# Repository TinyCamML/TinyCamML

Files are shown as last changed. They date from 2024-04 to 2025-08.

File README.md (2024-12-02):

# The Boron & OpenMV TinyCamML: 
### A small field-deployable camera with a cell connection.



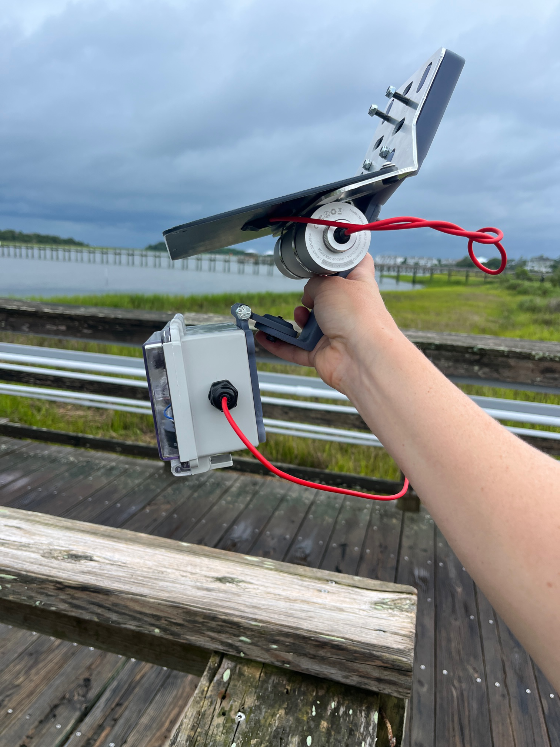
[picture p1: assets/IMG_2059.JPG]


### Overview:
Have you ever wanted to deploy a field camera, use machine learning on the images, and then send some message via cell? Us too! This repository is our work-in-progress on building the camera of our dreams. 

Our initial goal is to build cameras that overlook roadways, take pictures of the road, determine if the roadway is flooded, and send a simple message (i.e., 'flooded' or 'not flooded') via cell to a google sheet. 

The repository has multiple parts:

- a `Firmware` folder, that contains the OpenMV code and the Particle Boron code. The OpenMV handles taking pictures and using a ML model. The Boron handles publishing the ML model results to a google sheet via cell. 
- a `hardware` folder, that contains the 3D primnted parts, the circuit diagram, and the bill of materials for building the camera and the housing. 
- a `dev` folder, that has some snippets of code that were useful in building, testing, adn debugging the device
- an assets folder, that contains a [pdf of a build guide](assets/2024_12_02_BuildGuide.pdf) for the TinyCamML. If you have comments, you can add them to our [google document of the build guide](https://docs.google.com/document/d/1C9PLoJusVJ-cXYZn4gjNS5eJlwIkASh2FyWyaLo89QA/edit?usp=sharing)

### Do you want to be involved?:

- Get in touch with us, we would be happy to collaborate!
- Read through the repository to look at the files/code we provide.
-Check out the open issues and participate in our discussion.

### Code of Conduct:
We intend to foster an inclusive and respectful environment surrounding the contribution and discussion of our project. Make sure you understand our Code of Conduct.

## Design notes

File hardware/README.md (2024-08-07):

#  The Boron + OpenMV TinyCamML has 7 printed parts:

- 5 Mounting Parts
  -  Solar_panel_mount.stl
  -  Visor.stl
  -  Polycase_mount.stl
  -  XY_bracket
  -  Exteneder.stl
- 2 Baseplate Parts
  -  Baseplate.stl
  -  Antenna_mount.stl
######
## Images
# Full Build Assembly
  



# Mounting Assembly



# Baseplate Assembly



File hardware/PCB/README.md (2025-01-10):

# Directory for Carrier Board PCB.

Contains Eagle Schematic, Board Layout, CAM Data, and BoM for the PCB.

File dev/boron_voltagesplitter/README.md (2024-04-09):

# TestingVoltageSplitter

This firmware project was created using [Particle Developer Tools](https://www.particle.io/developer-tools/) and is compatible with all [Particle Devices](https://www.particle.io/devices/).

Feel free to replace this README.md file with your own content, or keep it for reference.

## Table of Contents
- [Introduction](#introduction)
- [Prerequisites To Use This Template](#prerequisites-to-use-this-repository)
- [Getting Started](#getting-started)
- [Particle Firmware At A Glance](#particle-firmware-at-a-glance)
  - [Logging](#logging)
  - [Setup and Loop](#setup-and-loop)
  - [Delays and Timing](#delays-and-timing)
  - [Testing and Debugging](#testing-and-debugging)
  - [GitHub Actions (CI/CD)](#github-actions-cicd)
  - [OTA](#ota)
- [Support and Feedback](#support-and-feedback)
- [Version](#version)

## Introduction

For an in-depth understanding of this project template, please refer to our [documentation](https://docs.particle.io/firmware/best-practices/firmware-template/).

## Prerequisites To Use This Repository

To use this software/firmware on a device, you'll need:

- A [Particle Device](https://www.particle.io/devices/).
- Windows/Mac/Linux for building the software and flashing it to a device.
- [Particle Development Tools](https://docs.particle.io/getting-started/developer-tools/developer-tools/) installed and set up on your computer.
- Optionally, a nice cup of tea (and perhaps a biscuit).

## Getting Started

1. While not essential, we recommend running the [device setup process](https://setup.particle.io/) on your Particle device first. This ensures your device's firmware is up-to-date and you have a solid baseline to start from.

2. If you haven't already, open this project in Visual Studio Code (File -> Open Folder). Then [compile and flash](https://docs.particle.io/getting-started/developer-tools/workbench/#cloud-build-and-flash) your device. Ensure your device's USB port is connected to your computer.

3. Verify the device's operation by monitoring its logging output:
    - In Visual Studio Code with the Particle Plugin, open the [command palette](https://docs.particle.io/getting-started/developer-tools/workbench/#particle-commands) and choose "Particle: Serial Monitor".
    - Or, using the Particle CLI, execute:
    ```
    particle serial monitor --follow
    ```

4. Uncomment the code at the bottom of the cpp file in your src directory to publish to the Particle Cloud! Login to console.particle.io to view your devices events in real time.

5. Customize this project! For firmware details, see [Particle firmware](https://docs.particle.io/reference/device-os/api/introduction/getting-started/). For information on the project's directory structure, visit [this link](https://docs.particle.io/firmware/best-practices/firmware-template/#project-overview).

## Particle Firmware At A Glance

### Logging

The firmware includes a [logging library](https://docs.particle.io/reference/device-os/api/logging/logger-class/). You can display messages at different levels and filter them:

```
Log.trace("This is trace message");
Log.info("This is info message");
Log.warn("This is warn message");
Log.error("This is error message");
```

### Setup and Loop

Particle projects originate from the Wiring/Processing framework, which is based on C++. Typically, one-time setup functions are placed in `setup()`, and the main application runs from the `loop()` function.

For advanced scenarios, explore our [threading support](https://docs.particle.io/firmware/software-design/threading-explainer/).

### Delays and Timing

By default, the setup() and loop() functions are blocking whilst they run, meaning that if you put in a delay, your entire application will wait for that delay to finish before anything else can run. 

For techniques that allow you to run multiple tasks in parallel without creating threads, checkout the code example [here](https://docs.particle.io/firmware/best-practices/firmware-template/).

(Note: Although using `delay()` isn't recommended for best practices, it's acceptable for testing.)

### Testing and Debugging

For firmware testing and debugging guidance, check [this documentation](https://docs.particle.io/troubleshooting/guides/build-tools-troubleshooting/debugging-firmware-builds/).

### GitHub Actions (CI/CD)

This project provides a YAML file for GitHub, automating firmware compilation whenever changes are pushed. More details on [Particle GitHub Actions](https://docs.particle.io/firmware/best-practices/github-actions/) are available.

### OTA

To learn how to utilize Particle's OTA service for device updates, consult [this documentation](https://docs.particle.io/getting-started/cloud/ota-updates/).

Test OTA with the 'Particle: Cloud Flash' command in Visual Studio Code or the CLI command 'particle flash'!

This firmware supports binary assets in OTA packages, allowing the inclusion of audio, images, configurations, and external microcontroller firmware. More details are [here](https://docs.particle.io/reference/device-os/api/asset-ota/asset-ota/).

## Support and Feedback

For support or feedback on this template or any Particle products, please join our [community](https://community.particle.io)!

## Version

Template version 1.0.2

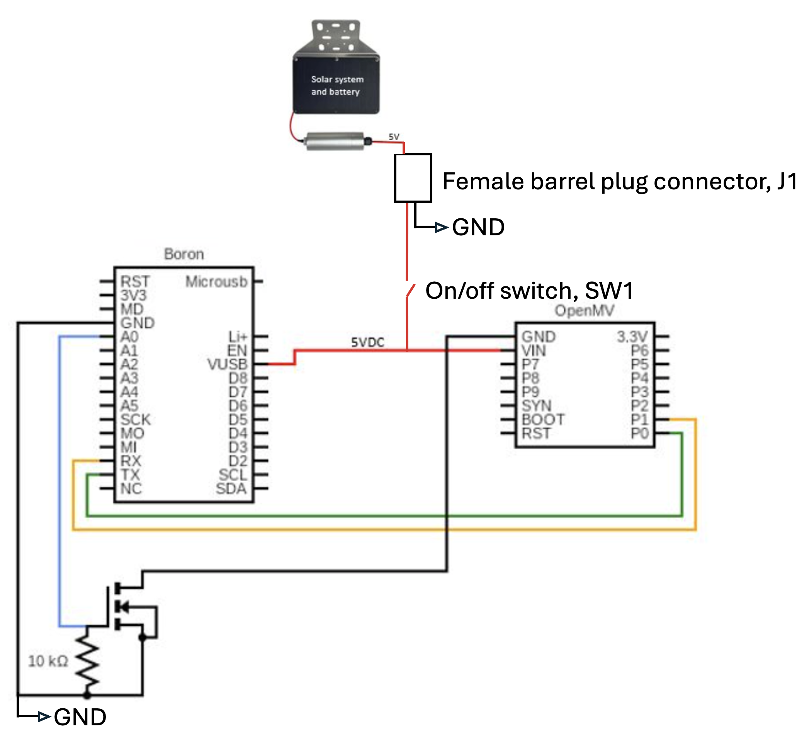
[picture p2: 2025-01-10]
hardware/TinyCamMLCircuit.png

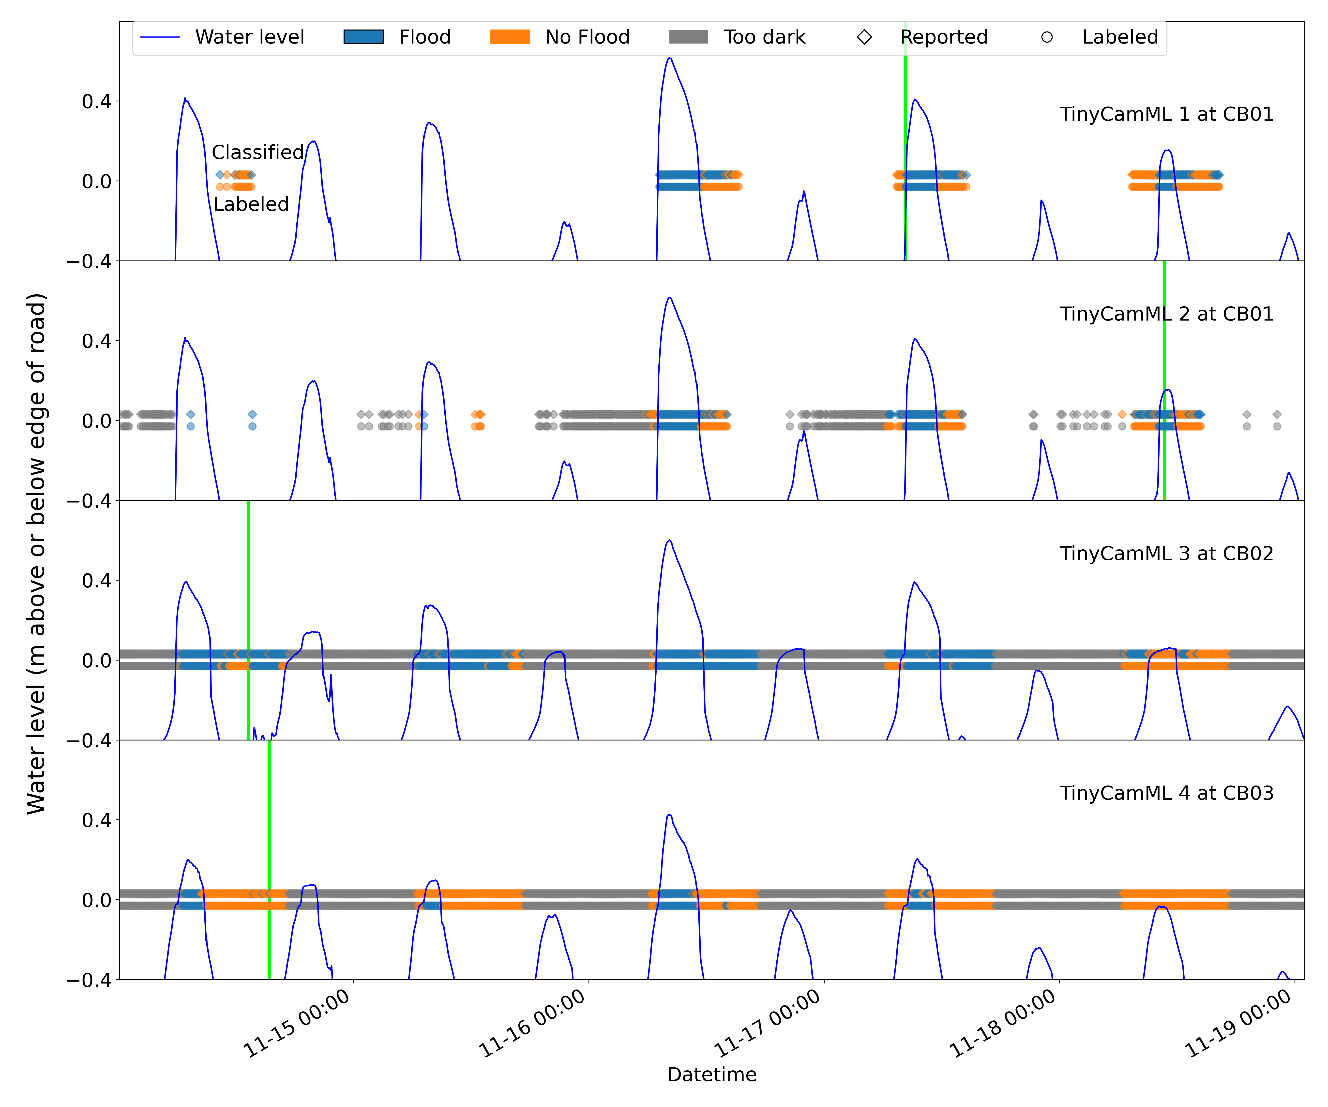
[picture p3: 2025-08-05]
Data Analysis/Figures/Figure3-WL.png

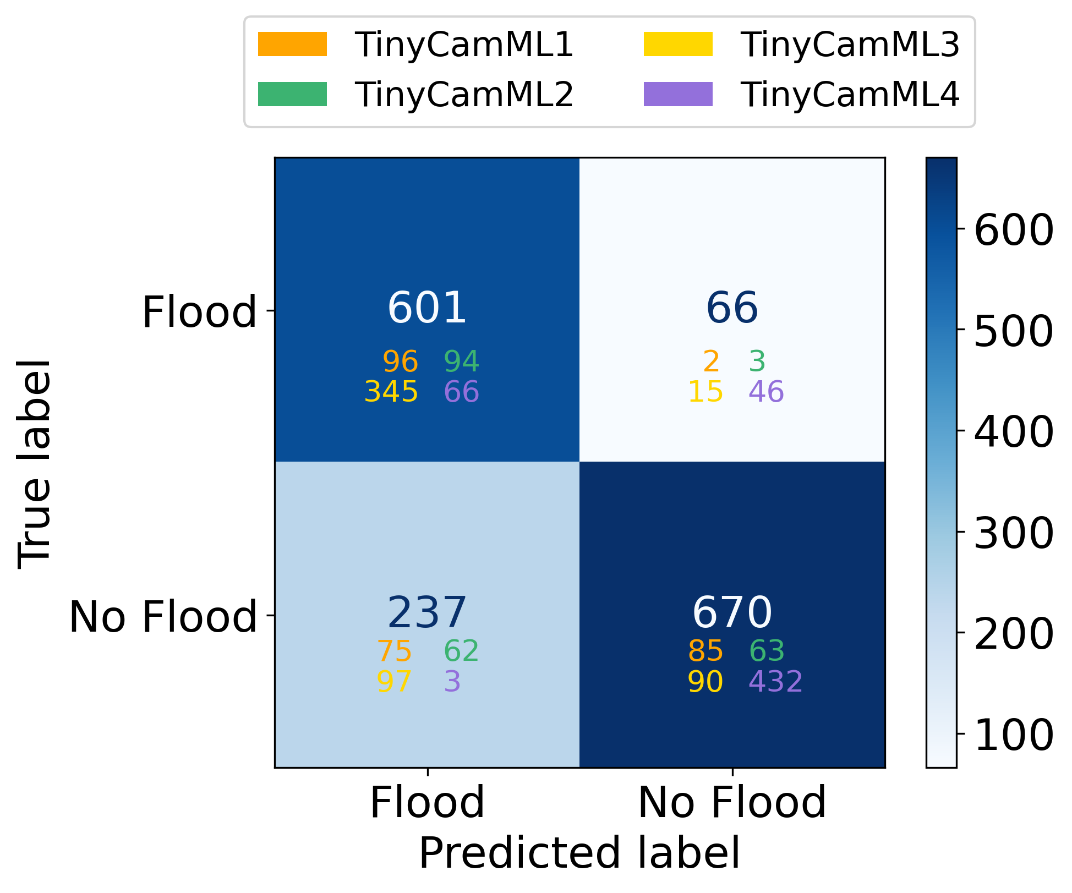
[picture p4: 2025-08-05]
Data Analysis/Figures/Figure4-CM.png

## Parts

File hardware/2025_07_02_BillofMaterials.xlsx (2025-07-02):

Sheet: BOM V2
 | For TinyCamML with PCB board
Parts | Price ($) | Picture | Link | Notes
Main Components
5W 5V solar system | 99 |  | https://voltaicsystems.com/5-watt-5-volt-35wh-solar-system/
OpenMV Cam H7 Plus | 85 |  | https://openmv.io/products/openmv-cam-h7-plus
Micro SD card | 10.94 |  | https://www.amazon.com/Samsung-Plus-Micro-Memory-Adapter/dp/B07349L1WS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 | Needed for the OpenMV
Particle Boron | 48.95 |  | https://store.particle.io/products/boron-lte-cat-m1-noram-with-ethersim-4th-gen
Custom TinyCamML PCB Board | 9.85 |  | https://github.com/TinyCamML/TinyCamML/tree/main/hardware/PCB | can order from oshpark.com
N Channel MosFET switch 30V/60a | 2.25 |  | https://www.adafruit.com/product/355
Resistors | 8.49 |  | https://www.sparkfun.com/products/10969
Switch slide | 0.44 |  | https://a.co/d/dqLmGOT | https://www.digikey.com/en/products/detail/same-sky-formerly-cui-devices/ds01-254-s-01be/11310868
Power jack for barrel plug | 0.79 |  | https://www.digikey.com/en/products/detail/w%C3%BCrth-elektronik/694102303002/5047520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
16 piece female headers | 0.82 |  | https://www.digikey.com/en/products/detail/sullins-connector-solutions/PPTC161LFBN-RC/810154
12 piece female header | 0.67 |  | https://www.digikey.com/en/products/detail/sullins-connector-solutions/PPTC121LFBN-RC/807231
Polycase WH-02-02 Clear | 21.03 |  | https://www.polycase.com/wh-02?gad_source=1 | assembly includes gasketed enclosure, 4 external mounting feet, and 4 screws
PG-9 size cable gland | 1.95 |  | https://www.adafruit.com/product/761
3D Printed Parts
For mounting the external housing: | 59.7 |  | https://formlabs.com/store/materials/tough-2000-resin/
XY Bracket |  |  | https://github.com/TinyCamML/Boron-and-OpenMV/blob/main/hardware/3D_Printed_Parts/XY_part%20_v4.stl
Extender |  |  | https://github.com/TinyCamML/Boron-and-OpenMV/tree/main/hardware/3D_Printed_Parts
Polycase Mount |  |  | https://github.com/TinyCamML/Boron-and-OpenMV/blob/main/hardware/polycase_mount_v5.stl
Solar Panel mount |  |  | https://github.com/TinyCamML/Boron-and-OpenMV/blob/main/hardware/3D_Printed_Parts/solar_panel_mount_v4.stl
Visor (optional) |  |  | https://github.com/TinyCamML/Boron-and-OpenMV/blob/main/hardware/3D_Printed_Parts/visor.stl
For mounting internal electronics:
Antenna Mount |  |  | https://github.com/TinyCamML/Boron-and-OpenMV/blob/main/hardware/3D_Printed_Parts/antenna_mount_v4.stl
Baseplate |  |  | https://github.com/TinyCamML/TinyCamML/blob/main/hardware/3D_Printed_Parts/baseplate_pcb_final.stl
Physical hardware
For the mount + housing:
1/4-in x 2-1/2-in Stainless Coarse Thread Hex Bolt | 0.3268 |  | https://www.mcmaster.com/catalog/130/3587/92198A552
1/4-in x 20 Stainless Steel Stainless Steel Nylon Insert Nut | 0.1254 |  | https://www.mcmaster.com/catalog/130/3644/91831A029
18-8 Stainless Steel Socket Head Screw, M5 x 0.8 mm Thread, 20 mm Long | 1.1662 |  | https://www.mcmaster.com/catalog/130/3558/91292A128
18-8 Stainless Steel Hex Nut M5 x 0.8 mm Thread | 0.6839 |  | https://www.mcmaster.com/catalog/130/3634/91828A241
4-40 Thread Size, 3/8" Long socket head screw | 0.2336 |  | https://www.mcmaster.com/92196A108/
M4 x 8mm Phillips thread rolling screws | 0.4112 |  | https://www.mcmaster.com/catalog/130/3444/90116A205
4-40 nuts | 0.1556 |  | https://www.mcmaster.com/91841A005/
#8-16 x .31” screws | 0 |  |  | comes with the polycase
Miscellaneous
Hoseclamps
Dessicant pack | 0.1798 |  | https://www.amazon.com/Dry-Premium-Packets-Desiccant-Dehumidifiers/dp/B00DYKTS9C?hvadid=695574715858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
O-ring grease | 1.49 |  | https://www.amazon.com/Ring-Grease-Waterproof-Insulating-Smoothness/dp/B0DKTPFCHC?hvadid=616863385083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
Sum | 354.6525

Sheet: BOM V1
 | For TinyCamML without PCB board
Parts | Quantity Needed to build one | Picture | Link | Notes
Main Components
5W 5V solar system | 1 |  | https://voltaicsystems.com/5-watt-5-volt-35wh-solar-system/
Female 3.5x1.1mm - MicroUSB | 1 |  | https://voltaicsystems.com/A101
OpenMV Cam H7 Plus | 1 |  | https://openmv.io/products/openmv-cam-h7-plus
Micro SD card | 1 |  | https://www.amazon.com/Samsung-Plus-Micro-Memory-Adapter/dp/B07349L1WS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 | Needed for the OpenMV
Particle Boron | 1 |  | https://store.particle.io/products/boron-lte-cat-m1-noram-with-ethersim-4th-gen
N Channel MosFET switch 30V/60a | 1 |  | https://www.adafruit.com/product/355
1 in x 1 in Protoboard | 1 |  | https://www.amazon.com/gp/product/B0BK76L5BD/ref=ox_sc_act_title_1?smid=A3M1L3DLN3L91I&psc=1 | This ones' rows are not shorted so in future orders, I'd recommend a different one
Resistors | 1 10k ohm resistor |  | https://www.sparkfun.com/products/10969
Polycase WH-02-02 Clear | 1 |  | https://www.polycase.com/wh-02?gad_source=1 | assembly includes gasketed enclosure, 4 external mounting feet, and 4 screws
PG-9 size cable gland | 1 |  | https://www.adafruit.com/product/761
3D Printed Parts
For mounting the external housing: |  |  | https://formlabs.com/store/materials/tough-2000-resin/
XY Bracket | 1 |  | https://github.com/TinyCamML/Boron-and-OpenMV/blob/main/hardware/3D_Printed_Parts/XY_part%20_v4.stl
Extender | 1 |  | https://github.com/TinyCamML/Boron-and-OpenMV/tree/main/hardware/3D_Printed_Parts
Polycase Mount | 1 |  | https://github.com/TinyCamML/Boron-and-OpenMV/blob/main/hardware/polycase_mount_v5.stl
Solar Panel mount | 1 |  | https://github.com/TinyCamML/Boron-and-OpenMV/blob/main/hardware/3D_Printed_Parts/solar_panel_mount_v4.stl
Visor | 1 - optional |  | https://github.com/TinyCamML/Boron-and-OpenMV/blob/main/hardware/3D_Printed_Parts/visor.stl
For mounting internal electronics:
Antenna Mount | 1 |  | https://github.com/TinyCamML/Boron-and-OpenMV/blob/main/hardware/3D_Printed_Parts/antenna_mount_v4.stl
Baseplate | 1 |  | https://github.com/TinyCamML/Boron-and-OpenMV/blob/main/hardware/3D_Printed_Parts/baseplate_v6.stl
Physical hardware
For the mount + housing:
1/4-in x 2-1/2-in Stainless Coarse Thread Hex Bolt | 1 |  | https://www.mcmaster.com/catalog/130/3587/92198A552
1/4-in x 20 Stainless Steel Stainless Steel Nylon Insert Nut | 1 |  | https://www.mcmaster.com/catalog/130/3644/91831A029
18-8 Stainless Steel Socket Head Screw, M5 x 0.8 mm Thread, 20 mm Long | 7 |  | https://www.mcmaster.com/catalog/130/3558/91292A128
18-8 Stainless Steel Hex Nut M5 x 0.8 mm Thread | 7 |  | https://www.mcmaster.com/catalog/130/3634/91828A241
M4 x 8mm Phillips thread rolling screws | 2 |  | https://www.mcmaster.com/catalog/130/3444/90116A205 | 2 for internal mount
4-40 Thread Size, 3/8" Long socket head screw | 2 |  | https://www.mcmaster.com/92196A108/ | 2 for anntenna mount
4-40 nuts | 2 |  | https://www.mcmaster.com/91841A005/
#8-16 x .31” screws | 4 |  |  | comes with the polycase
For mounting electronics:
M3 x 10 mm + 6 mm standoffs | 2 |  | https://www.amazon.com/HELIFOUNER-Standoffs-Assortment-Threaded-Motherboard/dp/B0B7SN13YR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 | for mounting the mini protoboard for voltage divider to baseplate
M3 x 6 mm screws | 2 |  | https://www.amazon.com/HELIFOUNER-Standoffs-Assortment-Threaded-Motherboard/dp/B0B7SN13YR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 | for mounting the mini protoboard for voltage divider to baseplate
M3 nuts | 2 |  | https://www.amazon.com/HELIFOUNER-Standoffs-Assortment-Threaded-Motherboard/dp/B0B7SN13YR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 | for mounting the mini protoboard for voltage divider to baseplate
M2.5 x 6mm screws | 4 |  |  | for mounting boron and openmv to baseplate
M2.5 nuts | 4 |  |  | for mounting boron and openmv to baseplate
M2.5 x 20 mm + 6 mm brass standoff | 2024-02-04 |  | https://www.amazon.com/HELIFOUNER-Standoffs-Assortment-Threaded-Motherboard/dp/B0B7SN13YR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 | for mounting the boron to baseplate
M2.5 x 15 mm + 6 mm standoff | 4 |  | https://www.amazon.com/HELIFOUNER-Standoffs-Assortment-Threaded-Motherboard/dp/B0B7SN13YR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 | for mounting the boron to baseplate
Miscellaneous
Jumper cables | 6 |  | https://www.adafruit.com/product/1950 and https://www.adafruit.com/product/1953 | for connecting all electronics together
Dessicant pack | 1 |  | https://www.amazon.com/Dry-Premium-Packets-Desiccant-Dehumidifiers/dp/B00DYKTS9C?hvadid=695574715858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
O-ring grease | 1 |  | https://www.amazon.com/Ring-Grease-Waterproof-Insulating-Smoothness/dp/B0DKTPFCHC?hvadid=616863385083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

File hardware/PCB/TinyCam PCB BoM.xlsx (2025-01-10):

Part | Price ($) | Qty to Build 1 | Picture | Link | Notes
N Channel MosFET switch 30V/60a | 2.25 | 1 | #VALUE! | https://www.adafruit.com/product/355
Resistors | 8.49 | 1 |  | https://www.sparkfun.com/products/10969 | 1 10k needed for OpenMV MOSFET Reset Assembly.
DC Power Jack 694102303002 | 0.79 | 1 | #VALUE! | https://www.digikey.com/en/products/detail/w%C3%BCrth-elektronik/694102303002/5047520
Dip Switch DS01-254-S-01BE | 0.50 | 1 | #VALUE! | https://www.digikey.com/en/products/detail/same-sky-formerly-cui-devices/DS01-254-S-01BE/11310868
Boron Board 16 Pin Female Header | 0.90 | 1 | #VALUE! | https://www.digikey.com/en/products/detail/sullins-connector-solutions/PPTC161LFBN-RC/810154 | Recommended female headers for the Boron Board by manufacturer, any 0.1" pitch female headers with a typical height of 0.335" should suffice
Boron Board 12 Pin Female Header | 0.73 | 1 | #VALUE! | https://www.digikey.com/en/products/detail/sullins-connector-solutions/PPTC121LFBN-RC/807231 | Recommended female headers for the Boron Board by manufacturer, any 0.1" pitch female headers with a typical height of 0.335" should suffice
OpenMV Board 8 Pin Female Header | 0.75 | 2 | #VALUE! | https://www.sparkfun.com/products/9279 | 2 included in Sparkfun OpenMV Kit.

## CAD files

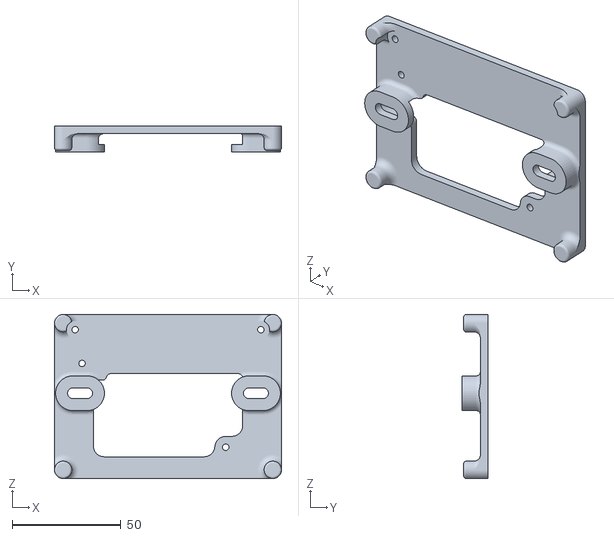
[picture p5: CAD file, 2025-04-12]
hardware/3D_Printed_Parts/baseplate_pcb_final.stl
104.5 x 12.0 x 75.5

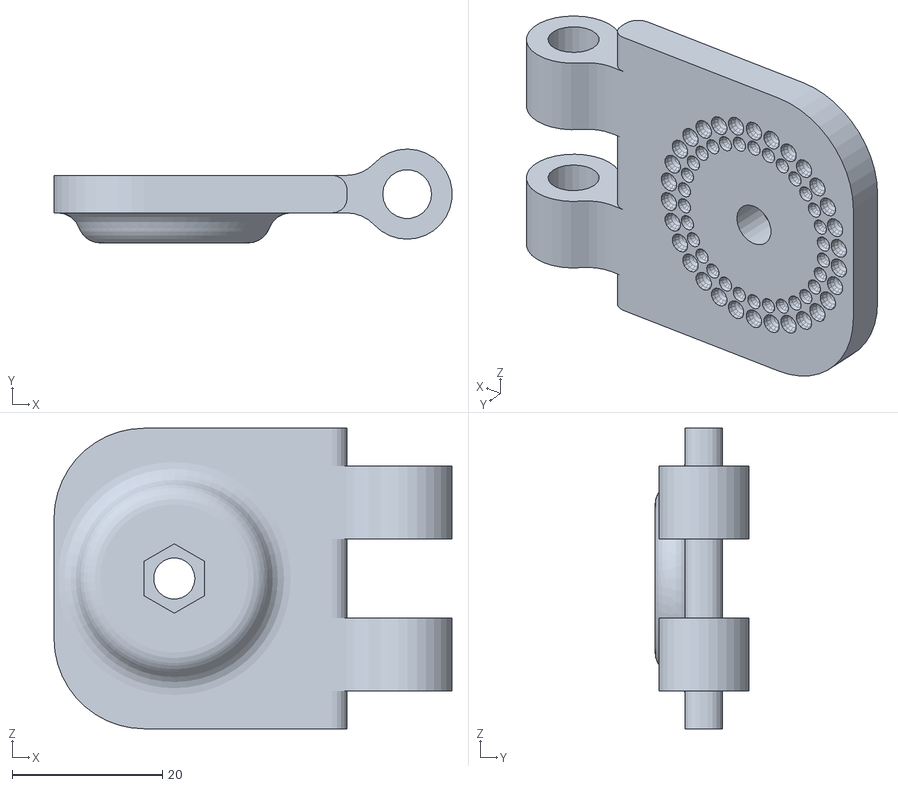
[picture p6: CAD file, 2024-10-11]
hardware/3D_Printed_Parts/XY_part _v4.stl
53.0 x 12.5 x 40.0

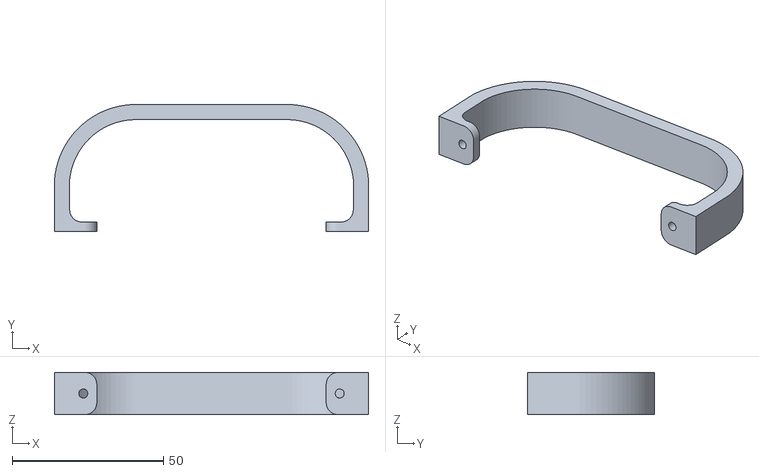
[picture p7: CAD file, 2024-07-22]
hardware/3D_Printed_Parts/antenna_mount_v4.stl
103.8 x 42.0 x 14.0

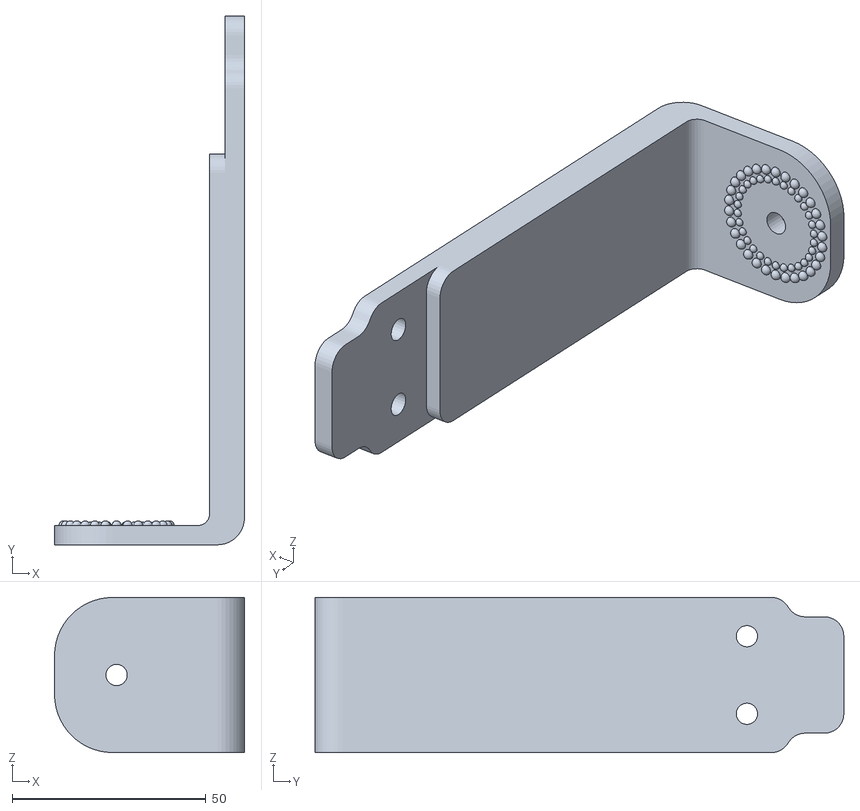
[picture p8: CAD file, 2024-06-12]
hardware/3D_Printed_Parts/extender_v3.stl
49.0 x 136.3 x 40.0

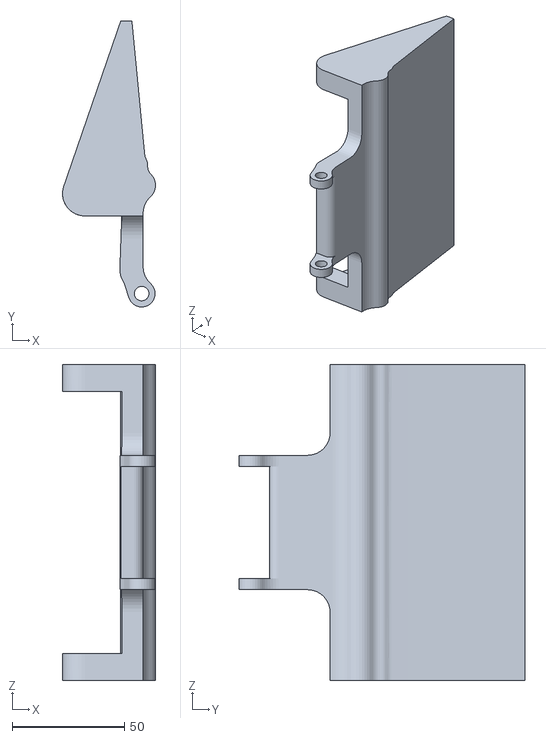
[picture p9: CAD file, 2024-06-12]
hardware/3D_Printed_Parts/visor.stl
41.5 x 127.6 x 141.0

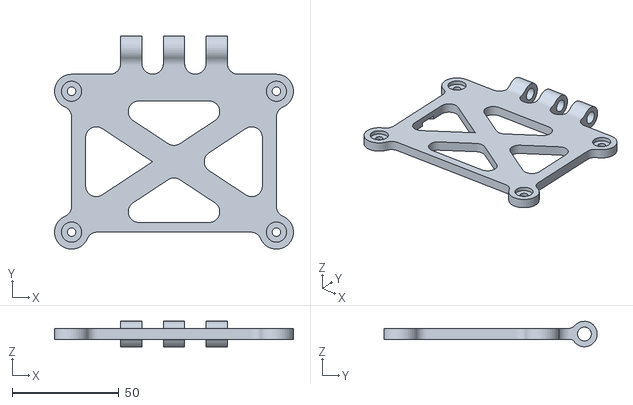
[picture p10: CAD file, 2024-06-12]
hardware/3D_Printed_Parts/polycase_mount_v5.stl
112.0 x 100.0 x 12.0

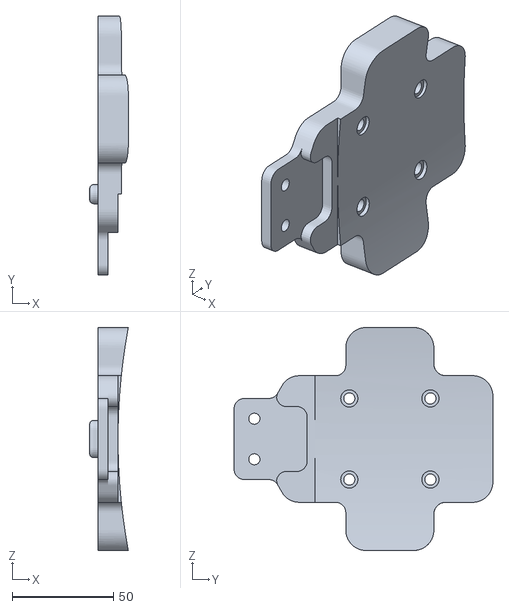
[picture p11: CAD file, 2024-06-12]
hardware/3D_Printed_Parts/solar_panel_mount_v4.stl
19.1 x 127.7 x 110.0

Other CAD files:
hardware/3D_Printed_Parts/CAD/Visor.ipt
hardware/3D_Printed_Parts/CAD/XY_part.ipt
hardware/3D_Printed_Parts/CAD/antenna_mount.ipt
hardware/3D_Printed_Parts/CAD/baseplate.ipt
hardware/3D_Printed_Parts/CAD/extender.ipt
hardware/3D_Printed_Parts/CAD/polycase_mount.ipt
hardware/3D_Printed_Parts/CAD/solar_panel_mount.ipt

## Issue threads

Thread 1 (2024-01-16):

Calculate power budget

SUPScientist, 2024-01-16:

SUPScientist, 2024-07-17:
Copying screenshot from @efarq's email on 16-Jul-24 titled "TinyCamML Update"
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
Image shows battery voltage in far right-hand column, very last value. In 2.5 hours, voltage goes from 4.28 to 4.21. Based on photos in same email, TinyCamML was set up inside, so no solar charging would have taken place. This rate of discharge seems very high and will need to be watched closely.

Options:
1. Reduce sample frequency. Currently 1 sample every 6 minutes (10/hr).
2. Look into other ways of reducing power draw when not sampling. E.g., cellular standby mode as configured here: https://github.com/TinyCamML/Boron-and-OpenMV/blob/1b7a30e41cd7efd28e730982d60f455be0a2741b/Firmware/Boron/src/TinyCamPublish.ino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.

ebgoldstein, 2024-08-12:
(for those reading this comment, please look at #5, which has some detail about optimizing sleep state. )

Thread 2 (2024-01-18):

Add Boron firmware to enable cellular transmission and publishing

BentleySettin, 2024-01-18:

BentleySettin, 2024-01-18:
@SUPScientist I added publishing code and will test it in the lab when I go back in next week, figured you may want to look at it too.

https://github.com/TinyCamML/Boron-and-OpenMV/blob/d570660cd345307e0bf74ff9e68ef27956a19899/PublishingCode

SUPScientist, 2024-01-18:
Looks like the file is missing its type (suffix) again as Evan has previously noted. We should look at your git/hub workflow to try to nip this in the bud. Here are some pointers that might help: https://docs.github.com/en/desktop/making-changes-in-a-branch/pushing-changes-to-github-from-github-desktop. Please recommit/push with the .ino suffix. In fact, it would be much better to push the entire project folder so that you have all the lib and config files here also, so please drag the whole project folder into GitHub desktop for committing/pushing (assuming you're using GH desktop). Let me know when that's complete and I'll take a closer look.

SUPScientist, 2024-01-18:
I added some comments to your .ino file with recommendations in https://github.com/TinyCamML/Boron-and-OpenMV/commit/3e9f44ababe1a75ce88f5301078db85598f61312. All comments start with `//PJB:` so you can find them easily. Some are critical, some are recommended.

BentleySettin, 2024-01-19:
Thank you, I edited the repo to look more like the example. I will recommit the other ones similarly

SUPScientist, 2024-01-22:
I'm going to keep being a stickler on this because I think file/project organization will make a HUGE difference in the next couple months and for the project's lifetime beyond this honors thesis...

This still isn't what I'd envisioned when I created that template. There are two problems with the Boron code.
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
1. There shouldn't be two .ino files, only ever one in a given folder. How would someone know which to choose?!
2. The .ino file should be organized within the full project that Particle workbench creates for you. That is, commit and push to github the *entire folder* that includes the lib and src folders, etc. See this screenshot for an example:
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
Having that full project folder in github is essential for sharing the configurations that you're using across the project (not just the lines of code in the .ino file that is currently shared).

BentleySettin, 2024-01-22:
Thank you for being detailed with this! I need and desire the criticism.

I am trying to drag the folder for TinyCamPublish into "add file" but it is not letting me. I think I am struggling with pushing the entire folder into Github.

SUPScientist, 2024-01-22:
I use the Terminal (command line interface or CLI) not GitHub desktop which is what I believe you use, so my workflow is different.
Does this help: https://docs.github.com/en/desktop/adding-and-cloning-repositories/adding-a-repository-from-your-local-computer-to-github-desktop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

This looks like a very relevant thread as well: https://github.com/orgs/community/discussions/21962

BentleySettin, 2024-01-22:
Okay I will look into these. I need to just commit set apart time from the lab to edit this all.

I ran an updated Publish code with publishing = 0 (OFF) and the boron is trying to connect to wifi still, flashing green. Based on the code it should result on cellular off and begin the switch states. It started flashing light blue which means it is trying to connect to internet which is when I terminated it immediatley.

BentleySettin, 2024-01-25:
@SUPScientist I may not be understanding this correctly. I have publishing to 0 and still the Boron tries to connect to internet and then even tries to connect to the cloud (cyan blinking). I have the if else statement purposely set turn cellular off just to test the rest of the code from the open-water-level sensor code.

Thank you!

SUPScientist, 2024-01-25:
Two thoughts:
1. Did you make sure to **flash application and DeviceOS (local)**? Maybe if the Boron you're using has a newer version of DeviceOS than the one that you're compiling/flashing for, there could be an internal conflict leading it to think it's supposed to try to connect automatically even if your firmware tells it not to.
2. I can review your script better once the whole project folder is committed to github.

BentleySettin, 2024-01-26:
Yes I did and it is committed [here](https://github.com/TinyCamML/Boron-and-OpenMV/commit/74e10d41a9f8b322990506688bc569c345647730).

SUPScientist, 2024-01-26:
What is the response to `particle serial identify` executed in the Particle CLI when the Boron is in listening mode? You may have to run it a few times to get a full response. Paste here only the DeviceOS version #, please (i.e., don't paste device ID).

BentleySettin, 2024-01-29:
system firmware version is 4.0.2

SUPScientist, 2024-01-30:
OK, doesn't seem to be a system firmware issue, then, so seems that it must be a user firmware (i.e., the .ino file) issue. Please keep committing changes to your .ino file as you work to troubleshoot this and I will continue to review to see if anything catches my eye. It'd also help to see better formatted code, such as what you get when you copy your script into https://codebeautify.org/cpp-formatter-beautifier and paste the results back into the .ino file. It shouldn't change anything other than aesthetics but it'll help follow the script more easily.

BentleySettin, 2024-01-31:
Will do. Does it take some time for a commit off github desktop to show in the repository? I committed updated code a few minutes ago and it is still not showing.

SUPScientist, 2024-01-31:
I use the command line interface (CLI) not GH Desktop, but I imagine the steps are the same:
- add changes to have them tracked in local repository (local means "on your computer")
- commit changes to local repository
- push changes from local repository to remote (which is the online GH)

My guess is that you haven't done step 3, maybe? https://docs.github.com/en/desktop/making-changes-in-a-branch/pushing-changes-to-github-from-github-desktop

BentleySettin, 2024-01-31:
Wonderful got it! You should be able to see the beuatified code [ here](https://github.com/TinyCamML/Boron-and-OpenMV/commit/cd6ed2f6fb4634cbe877f74eda70ccb887ce0185)

BentleySettin, 2024-02-05:
So I took out even the possibility for the Boron to connect to internet and publish to see if it would run through the switch states. It is continuing to flash green to connect to internet. Looking around in the code to make sure there is nothing there causing it to try to connect.

BentleySettin, 2024-02-14:
I am currently at the point where the OpenMV and Boron are able to turn on and off periodically and Boron is printing to the serial monitor data with all its variables. I found the correct format for the string in data. Currently in the serial monitor i am recieving the off images (�2☻) again in place of flood or No flood.

I am trying to determine if its a timing error which seems unlikely to me because the openMV is on the Boron's external interrupt.

SUPScientist, 2024-02-14:
Sounds like progress! Your last commit in this repo was last week, so I'm guessing you have newer code? Remember to please ALWAYS ALWAYS commit and push code after making changes and consider linking to specific files in your commit messages when relevant so that we can look closer.

BentleySettin, 2024-02-15:
https://github.com/TinyCamML/Boron-and-OpenMV/commit/a4b86a206f32f215cfd6dce1fff2837146b9b44e

Here is the newer code! committed and pushed !

BentleySettin, 2024-02-16:
I reverted back to the code used UART communications between Boron and OpenMV which has worked in the past. This is not working now and the openMV is showing no response to the digital write from the Boron. Looking at this now.

SUPScientist, 2024-02-16:
Recommend verifying OpenMV operations independently. Have you seen OpenMV print flood/no flood to its IDE's serial monitor when hooked up to its own USB cable (i.e., removing the Boron from the loop)? I recommend stripping back complexity until you get to something that verifies functionality, then building complexity back in one step at a time and verifying functionality at each step that you add.

BentleySettin, 2024-02-21:
Yes it works on the IDE serial monitor. I edited part of Evan's code which I will recommit if it works. Looks like the code from Evan kept the openmv on without actually falling asleep which is why i was previously using machine.sleep. Therefore this had the openmv flashing blue telling me it was reading and printing flood/no flood without any breaks. This may have been (1) causing the openmv to apear to be flashing blue  which I was interpretting as a hardware error (2) why the VS serial monitor keeps printing weird numbers because the timing is off.

Testing all this now.

BentleySettin, 2024-02-21:
@SUPScientist It works! Had to change a bit of both codes and recommitting now!

currently what i am looking at on VS serial monitor:

946684803,Flood,1.25,47.71
going to sleep
Sleeping for 56

ebgoldstein, 2024-02-21:
@BentleySettin - is this the commit? https://github.com/TinyCamML/Boron-and-OpenMV/commit/8916227a3f2c438f0915c54614141719e03c15b2.

if so, does it deal with this issue? I ask because I'm wondering if you can now close this issue?

If this issue still needs to be open, can you explain what the next steps are to be able to close the issue? I just want to make sure that all the comments/discussion in the issue is concretely connected to closing the issue at hand, and there is a clear roadmap to do it.

(i say this also because this issue has a title, but no real description/action items.. like 'step 1: do this, step 2, do that'... etc.)

BentleySettin, 2024-02-21:
Yes! Just reupdated it. https://github.com/TinyCamML/Boron-and-OpenMV/commit/a73a2d89ecc041749dbf780870dfa5da932aa2f8

I had to remove a hello statement but yes this issue is now solved

Closed 2024-02-21.

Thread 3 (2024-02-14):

Integrate google sheets with particle console

BentleySettin, 2024-02-14:

BentleySettin, 2024-02-16:
I want to verify I am taking the write steps @SUPScientist

I added a new integration using the google cloud platform because we agreed to send it to google sheets.

SUPScientist, 2024-02-16:
Noted. This is lower priority than getting the UART comms working again, so we'll focus on UART (flood/no flood) and then come back to this.

BentleySettin, 2024-02-21:
@SUPScientist With Uart comms fixed I believe I am ready to integrate! Whoot whoot

SUPScientist, 2024-02-27:
Unsure, sorry, but I'll try.  (Off-topic, but please continue to clean up the overall organization, including the homepage which has several repository descriptions that make them sound identical even though I think they're not. If you're stalled in coding work, there's plenty of documentation work (and thesis writing!) to be done as well so don't let me hold you up on general progress.)

BentleySettin, 2024-02-29:
@SUPScientist @ebgoldstein I am struggling to find where to edit the "About" page to update and better detail the descriptions. I looked up how even though I have done it before. It says use the settings gear in the upper right to edit but I do not have one.

Am I missing something? :)

SUPScientist, 2024-02-29:
See https://github.com/TinyCamML/.github/issues/1

SUPScientist, 2024-03-04:
Currently building the webhook to execute the publishing of data from Boron to Particle cloud to google sheets. Relies on an `eventName` which is currently `eventName = "FloodorNo"`:
https://github.com/TinyCamML/Boron-and-OpenMV/blob/a73a2d89ecc041749dbf780870dfa5da932aa2f8/Firmware/PublishBoronCode/src/TinyCamPublish.ino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

Do not change `eventName` or else integration will fail. More progress to come...

SUPScientist, 2024-03-04:
Read-only access to google sheet here: https://docs.google.com/spreadsheets/d/11ocVnjbdwYJO1UnGhrpfUw7a2iHKmkT3kHaA8BR1ntw/edit?usp=sharing

SUPScientist, 2024-03-04:
Following docs linked in https://github.com/COAST-Lab/Open-Water-Level/issues/24

SUPScientist, 2024-03-04:
Integration created and ready for testing. See https://github.com/COAST-Lab/Open-Water-Level/tree/main/Particle_Integration for documentation (which we ought to copy and paste here, too, including .js and .json files).
**IMPORTANT**: let's test this together in person to ensure correct functionality and non abuse of cellular connection. We'll set `PUBLISHING` to 1 here: https://github.com/TinyCamML/Boron-and-OpenMV/blob/a73a2d89ecc041749dbf780870dfa5da932aa2f8/Firmware/PublishBoronCode/src/TinyCamPublish.ino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

and `SECONDS_BETWEEN_MEASUREMENTS` to 360 here: https://github.com/TinyCamML/Boron-and-OpenMV/blob/a73a2d89ecc041749dbf780870dfa5da932aa2f8/Firmware/PublishBoronCode/src/TinyCamPublish.ino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

Then recompile/flash, then watch to see if the integration works. Leaving issue open till we can confirm functionality.

BentleySettin, 2024-03-12:
This works! Made recommended changes of setting publishing to 1 and measurements every 360 seconds.

Here is the google sheets which shows successful integration and collection: https://docs.google.com/spreadsheets/d/11ocVnjbdwYJO1UnGhrpfUw7a2iHKmkT3kHaA8BR1ntw/edit#gid=0

Closed 2024-03-12.

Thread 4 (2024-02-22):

Determine reason for communication interruptions when running for a long period of time (10 min +)

BentleySettin, 2024-02-22:
I am currently running the firmware for a long period of time to see if there are any issues. Looks like right now when this ran for about 10 minutes it printed "feeling restless" and collects flood or no flood sporadically. This is for about 3 minutes and then it seems to "come back to life" and run as normal. And to no apparent pattern it will not print flood/no flood at all. Seems to be a power issue but I am also wanting to see if it is a comm issue. Maybe the repetitions are so close to each other they struggle to run on sync?

Current step: I set runs for every 6 minutes, which would happen in the field, instead of every 1 minute. I want to see if this helps with this issue.

Next possible steps: Use USB for both devices (remove power wire) to determine if it is a power issue.

BentleySettin, 2024-02-22:
6 minute intervals worked 4 times (total of 24 minutes) before no longer reporting flood/no flood. When the two devices seem to be out of sync I can see the Boron turn on, wait 2 seconds, turn off, and then the blue LED from the OpenMV which signifies it ran through its loop. The blue light after the Boron turns on and off shows a possible descripency in time. However, with the 6 minute test the openmv did not even flash blue.

BentleySettin, 2024-02-22:
Update: Retried this trial and it ran successfully for 42 minutes.

BentleySettin, 2024-03-12:
These issues do not occur when the interval time was increased to 6 minutes.

Closed 2024-03-12.

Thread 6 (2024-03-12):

Not registering Flood or No Flood

BentleySettin, 2024-03-12:
The boron is inconsistently reporting back flood/No Flood. The VS serial monitor shows empty for this report. I am trying to figure out if this is a Boron or OpenMV issue or possible power supply.

I plugged both into USB (removing the connecting power wire) and they reporting of Flood is consistent now.

SUPScientist, 2024-03-12:
Can you be more specific about

> I plugged both into USB (removing the connecting power wire)

That is, do you mean you used one USB cable per device?

Did you try the new solar panel + battery to supply 5 V to both (and especially the OpenMV which has higher voltage needs than Boron)?

BentleySettin, 2024-03-13:
Here is what I am seeing where there is no report of flood or no flood:

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

Here is what I am seeing when there is a report:
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

BentleySettin, 2024-03-13:
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

The last flood you see in the google sheet is from me pressing restart on the Boron. I know we discussed this would not be helpful because it would cause a total reset and not collect real time but I used it to see if it would help report Flood/No Flood and it did. A manual reset that helped both devices communicate on the "same page" makes me wonder if there is a stacking of the communication that disrupts the entirety of UART communications. As said before this could still be rooted in a power supply issue.

SUPScientist, 2024-03-13:
Ah, this might be the clue! Not sure, but this part

> A manual reset that helped both devices communicate on the "same page" makes me wonder if there is a stacking of the communication that disrupts the entirety of UART communications.

seems especially interesting. I hadn't noticed this pattern because it just looks random to me, but if it often starts with a good UART communication and then falls apart over time, it could be related to the handling of the serial communications more than the power (though could still be the latter).

See this code chunk from a somewhat similar system (Boron communicating with peripheral sensor via UART) where I end and then restart serial communications every time through the loop. It seems like overkill (and might not be optimal coding), but it solved a similar issue. Give it a shot and test again for a similarly long period to see if you can achieve reliable serial comms.

https://github.com/SUPScientist/CellpHOx/blob/77a79682f5c87aff60315a78a794554290044e75/10_CellpHOx_Vipul_PJBImproveTiming/src/10_CellpHOx_Vipul_PJBImproveTiming.ino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

BentleySettin, 2024-03-14:
@SUPScientist

I added this code and updated it [here](https://github.com/TinyCamML/Boron-and-OpenMV/commit/a73a2d89ecc041749dbf780870dfa5da932aa2f8)

I had responses for the first few cycles and then it is has returned to no reporting.
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

BentleySettin, 2024-03-14:
I returned to have a USB powering both devices to continue to refine the problem. I have noticed a new pattern on the openMV. Every 4-5 cycles the openMV flashes green a few times then stops. Following this event the Boron skips a report. I am looking more into this green flashing as a possible issue.

@ebgoldstein any ideas? Based on the web it seems to be the bootloader.

BentleySettin, 2024-03-22:
The problem has become more and more common of no reporting while connected to the solar panel. When I attach both devices to USB I have no issues at all. When I attach the solar panel and battery to Boron the OpenMV will keep a white light on which seems to be related to power based on openMV forums.

Based on what I am seeing there seems to still be a power issue.

BentleySettin, 2024-03-22:
Woohoo another issue...

I left both plugged in to USB running for about 30 minutes and then recieve a white flashing from the openMV.
When I connect Boron to usb + battery the openMV is unresponsive still.

I have done some research on this. Multiple people seem to struggle with openMV for more than 30 minutes of running. I am looking into possible updates for the camera, however, am a bit tentative because in one of the forums the creator says       "given how small our operation is some firmware updates brake things. But, generally you want to update the camera". I am still trying to figure out what all these LED flashing or not flashing means based on each scenerio.

@SUPScientist any ideas?

SUPScientist, 2024-03-22:
If you believe it's a power issue, I recommend checking the charge of the battery attached to the solar panel.

Recommended steps:
1. Use multimeter to determine battery charge
2. Use multimeter to determine VUSB charge (i.e., voltage going from Boron to OpenMV)
3. If battery is depleted, you may have to manually charge it. Read up on the battery/charger (https://voltaicsystems.com/5-watt-5-volt-35wh-solar-system/) and find a good/safe way to charge it. I imagine you can charge it directly via USB from, e.g., a computer or AC/DC adapter brick (such as standard phone charger).

SUPScientist, 2024-03-22:
> Woohoo another issue...

Please put new issues in a new Issue ;)

BentleySettin, 2024-03-27:
Solar panel charged and now registering flood/no flood with consitency. The lack of reporting from the OpenMV was a battery issue solved by charging the solar panel.

SUPScientist, 2024-04-02:
@BentleySettin, saw you closed this last week and described the resolution. Then saw you reopened it! Is it not resolved? If not resolved, please provide:
- How it should work
- How it is working instead
- Hypothesized root cause of the problem and how you will try to troubleshoot/resolve it.

BentleySettin, 2024-04-03:
I should be consistently have a report of flood or no flood but I am currently seeing sporadic reports. I gave it some time and am realizing it may "just be" a cellular issue. Boron flashes green for a while then will either flash the light blue once or twice or just time out of trying to find cellular.

I moved the devices to find better connection

BentleySettin, 2024-04-03:
@SUPScientist I am recieving no information on the google sheets even though I am watching the devices turn on and off.

I am seeing a variety of LED patterns such as; Boron flash yellow, then light blue, then green.

Could there be something with the antenna?

BentleySettin, 2024-04-03:
Another update:

I plugged openMV into computer to check out file folder and see if any possible updates because I keep recieving a white flashing light every 30 minutes. On the file folder there was this added page that said " FATAL ERROR:
MemManage ".

Trying to determine how to deal with this image.

SUPScientist, 2024-04-03:
> I am seeing a variety of LED patterns such as; Boron flash yellow, then light blue, then green. Could there be something with the antenna?

Boron LED status codes are described here: https://docs.particle.io/troubleshooting/led/boron/. Blinking yellow should only happen when you're flashing code or major errors: https://docs.particle.io/troubleshooting/guides/device-troubleshooting/device-blinking-red-yellow-or-frozenno-led/.

ebgoldstein, 2024-06-12:
i think we can close this, as it was likely related to memory growth (#14) when device was run for 30 mins or more. I have a fix for that now, which is committed to github (https://github.com/TinyCamML/Boron-and-OpenMV/commit/730f992ca492b153a643b581057a881996611d9b)... please reopen if needed, but i think we can close...

Closed 2024-06-12.

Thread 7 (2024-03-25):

Apparent power supply issue with OpenMV on solar power

SUPScientist, 2024-03-25:
Opening a new issue in this repo based on issue described here: https://github.com/TinyCamML/OMVmodel/issues/11. Issue pertains to setup where Boron and OpenMV are connected and powered by solar panel/battery and belongs in this repo.

@BentleySettin writes:
> The OpenMV is displaying a variety of LEDs when connected to a variety of power sources. When the Boron and OpenMV are connected to solar panel and battery there is an indefinite white light. When the Boron and OpenMV are connected USB via my computer and battery there is a flashing white light. When both devices are connected to USB there are no LED's besides an occasional green flashing that lasts for a few seconds.

@BentleySettin, is the following accurate?

### Expected behavior:
- No LEDs flashing on OpenMV
- "flood" or "no flood" string should be communicated from OpenMV to Boron over UART and printed in serial monitor/transmitted over cellular

### Actual behavior:
- White LED shines on OpenMV
- "flood" or "no flood" string is only intermittently communicated from OpenMV to Boron over UART

### Steps to reproduce behavior:
- Boron powered by solar panel and battery into micro-USB port on Boron
- OpenMV powered by VUSB from Boron which should pass power directly from Voltaic solar panel/battery through micro-USB port through VUSB pin to OpenMV

SUPScientist, 2024-07-17:
Update following email from @efarq on 16-Jul-24 titled "TinyCamML Update":

Issue not resolved but not necessarily related to (solar) power supply.

### Expected behavior:
"Flood" or "No Flood" to show up in transmitted data string from Boron.

### Actual behavior
"Flood" or "No Flood" shows up for first 17 samples (96 minutes) then ceases. See screenshot of data from Sheets:
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

Other symptoms:
Photos cease to be saved to SD card at the same time that "Flood" or "No Flood" no longer reported, and images that were saved appear to be a combination of two different frames. Appears to indicate problem with OpenMV side.

### Suggested tests
1. Restart and run everything "fresh" again to see if failure timing is deterministic
2. See https://forums.openmv.io/t/sleep-mode-wakeup-with-external-interrupt/767/2. Especially

> Anyway, you shouldn’t put code… in your call back. Instead, just have a very simple method that immediately exits. What will happen is that after standby the camera will wake up again and continue to execute code. Note that you need to completely re-init the camera after this happens.

I'm not the OpenMV expert (@ebgoldstein, can you take a look at this hypothesis?) but wonder if our OpenMV (re)initialization is happening above the callback and that is causing the issues. If you move
https://github.com/TinyCamML/Boron-and-OpenMV/blob/1b7a30e41cd7efd28e730982d60f455be0a2741b/Firmware/OpenMV/PublishOpenMV.py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
up to immediately after the import statements, does that make a difference?

ebgoldstein, 2024-07-18:
I am also interested in what @SUPScientist mentioned, if it is a deterministic time..

 In #26 I updated the image save routine, the text file generation, and added a line to the txt file to make sure to track memory growth..

@efarq , I recommend checking out the PR, and using this new firmware to retest the openMV...

ebgoldstein, 2024-07-18:
i think what i want to see is the Boron google sheet and the OpenMV csv/txt sheet for this new test.... as well as the photos, to see if they have that half/half error

SUPScientist, 2024-07-18:
If #26 doesn't resolve the issue, I'd still be interested in following code structure closer to https://forums.openmv.io/t/sleep-mode-wakeup-with-external-interrupt/767/2. Specifically, `sensor.reset()` and other config details in the while loop. I'm admittedly less familiar than I'd like with how micropython and openmv handle the wake from interrupt/callback when sleeping.

ebgoldstein, 2024-08-07:
I'm going to close this for now...

Closed 2024-08-07.

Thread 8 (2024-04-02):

Initial enclosure design

SUPScientist, 2024-04-02:
### Need
Design housing/enclosure for Boron, OpenMV, internal lipo battery (if needed), and external solar panel/battery.

### Steps
- [x] Select polycase with dimensions to fit all parts
- [x] Design placement for penetrators/cable glands on polycase
- [x] Design placement for camera and window/sun glare shield if needed
- [x] Design bracket to mount polycase and solar panel together

SUPScientist, 2024-04-02:
Some reference materials exist in related repo, such as a bracket for Voltaic panel/battery and polycase: https://github.com/COAST-Lab/Open-Water-Level/tree/main/Fabrication/Enclosure%20and%20Assembly/Voltaic-Polycase-Bracket. Note that bracket was designed for printing on Form 3 and was made shorter than might be desired given printer limitations. Designed for polycase here https://github.com/COAST-Lab/Open-Water-Level/blob/main/Fabrication/Datasheets/polycase_2d_drawings.pdf and Voltaic bracket here https://github.com/COAST-Lab/Open-Water-Level/blob/main/Fabrication/Datasheets/Voltaic_Bracket_BK102_dwg.pdf.

SUPScientist, 2024-04-02:
@ebgoldstein, I tried to assign this to @jacobstasiewicz but he's not a member of the org and I'm not an owner/don't have permissions to add new members. Could you pull him into the org?

ebgoldstein, 2024-04-02:
@jacobstasiewicz, I'm looping you into this issue re: designng enclosure for the openMV+particle system

To make everyone aware, Jacob and I discussed:
- we need a hole for a cable gland,  but we might not need other cuts.
- 3D printing a mounting system
- I will design a PCB with female headers for the 2 boards to pop into

We discussed options for the camera field of view:
- do we want a clear lid or solid lid?
- do we want a camera dome?
- do we want a hile& visor

ebgoldstein, 2024-04-09:
finding or deisgn/printing a bracket connecting polycase to solar panel (https://github.com/COAST-Lab/Open-Water-Level/blob/main/Fabrication/Enclosure%20and%20Assembly/Voltaic-Polycase-Bracket/Polycase-Voltaic-Bracket%20v12.stl)

SUPScientist, 2024-04-09:
If this design serves as the basis for a new design for this TinyCamML project, please let me know early in the design process.

Two improvements needed to that design:
1. Slots for mating the solar panel bracket with the custom 3D printed bracket referenced above could be shifted a couple mm for better alignment
2. It'd be valuable to have material under the top mounting holes on the solar panel bracket to avoid tightening a hose clamp in the top to the extent that it pulls the top of the solar bracket flush with a tree which would result in a non-perpendicular camera angle

ebgoldstein, 2024-04-23:
@jacobstasiewicz:

can you commit the design files and a draft BOM to a new folder in this repository called 'hardware' then close this issue?

I will open a range of issues related to hardware design based on our discussion today, they will all be tagged with 'enclosure' and 'enhancement'

ebgoldstein, 2024-06-12:
this is done... #22 is focused on uploading files

Closed 2024-06-12.

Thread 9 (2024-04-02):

Monitor external solar panel/battery voltage

SUPScientist, 2024-04-02:
### Need
Want to be able to monitor voltage of external solar panel/battery which is plugged into Boron's V_USB via the micro-USB socket.

### Challenge
Particle has methods for monitoring VBATT where a LiPo battery would be connected (via the FuelGauge methods: https://docs.particle.io/reference/device-os/firmware/#fuelgauge) but unclear how to monitor V_USB. Assumption may be that V_USB comes from a stable power supply and does not need to be monitored.

### Steps to Solve
- [ ] Read Particle docs
- [ ] Check Particle forum/post
- [ ] Could feed into a Particle GPIO via voltage divider and use analog input if needed, but this wastes power

SUPScientist, 2024-04-02:
@efarq, can you check this out?

SUPScientist, 2024-04-02:
Here's a reference design for a voltage divider that Particle uses to measure the battery voltage on an Argon: https://docs.particle.io/reference/device-os/api/battery-voltage/battery-voltage-photon-2/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. The voltage on VUSB on the Boron will be higher but the nominal resistances used here are helpful nonetheless. At ≈ 1 MΩ, current wasted will be ≈ 5 µa which isn't too bad.

ebgoldstein, 2024-04-03:
fuel gauge does not seem to work with usb input: https://community.particle.io/t/fuel-gauge-reading-on-the-usb/62568/3

SUPScientist, 2024-04-03:
Yes, I didn't think the fuelgauge would work but it was worth double-checking. See the voltage divider reference above for a proposed solution. I think it will be critical to have solar panel/battery monitoring ability and a voltage divider is very easy to implement and for @ebgoldstein to include in the PCB.

SUPScientist, 2024-04-09:
@efarq to design/test voltage divider to scale 5 V nominal solar panel output down to 3.3 V max acceptable Boron ADC analog input. Using equation Vout = Vin*(R2/(R1+R2)) in standard voltage divider circuit, R2 to be ≈ 2 MΩ and R1 to be rounded up to nearest available resistor that keeps Vout ≤ 3.3 V.

efarq, 2024-04-09:
Just following up - I think I got it worked out! With Phil's help, I found that R1 = 1.125 megaohms, so I rounded it up to 1.3 megaohms, and R2 = 2 megaohms. Then I set up the Boron with some resistors (photo and circuit diagram attached) and ran the code on it. The Boron V(out) was consistently reading about ~2.7V while it was receiving usb power from my laptop. I checked with the multimeter, and that matched what the Boron was saying too.

I'm uploading the script folder to the Firmware folder, and the Boron+resistors+breadboard are on the counter in Phil's lab. Let me know if anything looks like it needs to be changed.
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

SUPScientist, 2024-04-09:
Great, thanks, @efarq. Nice work. I see the test script in your commit here https://github.com/TinyCamML/Boron-and-OpenMV/commit/e2b713a82b8a3a851c1bc34a9584dc5fcb082bdf and in the new subdirectory here https://github.com/TinyCamML/Boron-and-OpenMV/tree/main/Firmware/TestingVoltageSplitter.

To close this issue, I recommend the following:
1. Create a branch of this repo
2. Integrate solar panel/battery voltage monitor firmware into main Boron firmware in that branch
3. Test new firmware
4. Iterate between 2<—>3 as needed
5. Once firmware works as desired, merge branch back into main.
6. Close issue with link to merge

(@ebgoldstein, workflow seem appropriate to you? As we add teammates here, I'm more than open to thinking through desired github workflow together/following your lead.)

SUPScientist, 2024-04-24:
Great! That looks good at a first glance. Confirming that you tested this on the hardware? If so, please say so and click "close with comment."

I recommend removing the percent charge variable and report. Battery charge is non-linearly related to voltage (google "battery discharge curve" for visuals) and can easily be inaccurate. Voltage will suffice. No branch/pull request needed for that change; just remove relevant parts of .ino file and recommit/push, please.

efarq, 2024-04-26:
Yes, I tested it on the Boron and OpenMV that bentley was using, and it seems to work.

efarq, 2024-06-25:
I'm reopening this so I remember to look at it this week. I just need to double check the code/voltage with a multimeter for this because it's still reporting about 2.8-2.9 V when plugged into usb power. I thought I scaled it up properly by multiplying by an extra ((R1 + R2) / R1)

https://github.com/TinyCamML/Boron-and-OpenMV/blob/3a03ea4b75fd1438a5236e86fadcb9e209097110/src/boron/src/TinyCamPublish.ino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

SUPScientist, 2024-07-17:
Solved with https://github.com/TinyCamML/Boron-and-OpenMV/commit/8a047e3b0cbdd27e7818fff782918f5fbd4ddb85

efarq, 2024-07-22:
I'm actually not 100% convinced this is truly resolved. So currently, I have the TinyCamML running off of my computer usb, so it should be reading pretty close to 5V. However, it is reporting values around 4.36V, suggesting maybe my scaling is off? Any ideas of things for me to review?
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

SUPScientist, 2024-08-12:
Reopening based on @efarq's comment above and preliminary data showing no apparent trend in voltage (screenshot below from analysis in https://github.com/TinyCamML/Boron-and-OpenMV/blob/main/analysis/tinyCamML_analysis_20240812.ipynb).

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

Notes:
- Unclear if data show anything unexpected after relatively short deployment
- Hypothesis: a voltage regulator on Voltaic panel/power supply may "try" to supply 5 V no matter what the battery's actual charge is and we may not be able to monitor this after all. Unsure, but more investigation needed.

efarq, 2024-09-27:
Closing this now after talking to Voltaic Systems and having them tell us there is no way to monitor battery voltage from the solar panel, likely due to a voltage regulator

SUPScientist, 2024-09-27:
Seems appropriate to close; I just referenced this in a new issue at https://github.com/TinyCamML/Boron-and-OpenMV/issues/43 so that this idea, even if not the solution pursued in this issue, is retained.

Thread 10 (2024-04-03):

Smaller Solar setup

ebgoldstein, 2024-04-03:
I think the Solar setup we have right now is perfect for a first pass, but we should likely be able to make it smaller. this can be trial and error w/ panels and batteries, and knowing the microcontroller constraints:

- An active OpenMV R2 w/uSD card requires 170mA @ 3.3V (https://openmv.io/products/openmv-cam-h7-r2)
- Particle boron (from USB) seems to want 500mA @ 3.3V (https://docs.particle.io/reference/datasheets/b-series/brn404x-datasheet/)..

additionally, the devices can power off/sleep during nighttime hours...

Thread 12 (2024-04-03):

Fix wiring diagram

SUPScientist, 2024-04-03:
### Problem
Current wiring diagram here https://github.com/TinyCamML/Boron-and-OpenMV/blob/main/Files/Circuit-Diagram.png incorrectly shows power from 5V battery attached to solar panel inputs to Boron and OpenMV.

### Fix
Show single source branching off to Boron and OpenMV similar to the following screenshot:
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

SUPScientist, 2024-04-26:
Noticed this morning in Bentley's excellent honors thesis defense that the battery symbol is technically backwards. + connection should come from side with longer line and would be appropriate to show a ground net attached to shorter line side.

Closed 2024-07-26.

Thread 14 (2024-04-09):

mem management

ebgoldstein, 2024-04-09:
From @BentleySettin :

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

ebgoldstein, 2024-04-09:
need to look at garbage collection: https://docs.openmv.io/library/gc.html

one simpel thing is to save the current me state... so `gc.mem_free` or `gc.mem_alloc` to record what is oging on w/ memory during the 30-40 mins

ebgoldstein, 2024-06-12:
ok, this should be fixed now... I observed the memory growth, now we explicitly call garbage collection with `gc.collect` right before the OpenMV sleeps... and memory does not grow.. i am testing a long run right now..

Closed 2024-06-12.

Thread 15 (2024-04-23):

Simplify BOM and needed hardware

ebgoldstein, 2024-04-23:
Ideally it is all M5, M2, M2.5

we should also have a McMaster cart set up as a link with all needed parts.

ebgoldstein, 2024-05-28:
can close this - its all M5 and a 1/4 inch bolt on the pivot

Closed 2024-05-28.

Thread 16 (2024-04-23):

Antenna Mount

ebgoldstein, 2024-04-23:
Iterate on antenna placement - this will likely be trial and error

ebgoldstein, 2024-05-28:
we have a prototype, so lets close for now

Closed 2024-05-28.

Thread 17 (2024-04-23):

Mechanism to lock the bracket for polycase vertical tilting

ebgoldstein, 2024-04-23:
We need a way to lock this. Ideas include:

- bicycle style quick release skewer
- rubber gaskets for more friction
- some sort of coating/spray?
- ...

ebgoldstein, 2024-04-25:
i think the easiest solution here is to include space for gaskets, and then the tightened bolt will hopefully apply enough pressure for friction to hold it in place...

Another option is a torque hinge, but i still worry that envt changes (temp/pressure/humidity/wind/animals) will cause it to move unexpectedly...

A final idea is to have an immobile bracket, but then bring a range of different angles to each deployment)...

my pref right now (as a first step) is to test a hinge with gaskets...

ebgoldstein, 2024-06-12:
lets close this for now, seems like hte vertical tilt will hold

Closed 2024-06-12.

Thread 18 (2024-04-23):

first draft parts printed

ebgoldstein, 2024-04-23:
print parts for dry fitting/inspection

ebgoldstein, 2024-04-25:
@jacobstasiewicz - can you post a picture of the parts here when they are done/fitted? then feel free to close the issue

jacobstasiewicz, 2024-04-25:
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

Closed 2024-04-25.

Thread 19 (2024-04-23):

send materials to JS

ebgoldstein, 2024-04-23:
ship parts to @jacobstasiewicz
- polycase (expected to arrive Wed, will ship ASAP)
- mounting screws
- baseplate
- boron

ebgoldstein, 2024-04-24:
Done as of today - also included a PG-9 cable gland

Closed 2024-04-24.

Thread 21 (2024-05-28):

test hose clamp mounting

ebgoldstein, 2024-05-28:
iterate on voltaic mount design, specifically having hose clamp holes instead of using all voltaic panel mount holes as guide holes for the 3d printed piece

ebgoldstein, 2024-06-12:
this is in progress..

jacobstasiewicz, 2024-06-12:
bracket has been redesigned

Closed 2024-06-12.

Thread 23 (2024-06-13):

send datetime from Boron to OpenMV

ebgoldstein, 2024-06-13:
this is likely a uartread w/ OpenMV

ebgoldstein, 2024-06-13:
i assigned this to @efarq , but I am also helping with this

efarq, 2024-06-21:
For the particle boron code, I added a Serial1.println(real_time) after the Serial1.readstring() so that it would print its datetime to the OpenMV.

For the openMV code, I added a curr_time = str(uart.read()) to after the uart.write() function, so it would read the datetime for the boron.

Currently, this is not working. I am wondering if there needs to be something like a serial1.end and begin to reset the channel before trying to exchange the datetime. Or perhaps an "if serial1.available()" statement before it tries to send the datetime. Any other ideas @ebgoldstein @SUPScientist ?

SUPScientist, 2024-06-21:
First, re: process: can you create a branch (maybe you already have), commit code, and add a direct permalink to the relevant chunk(s) in this issue here?

Also, the more description about what is expected behavior vs. what you're seeing (not working), the better.

Second, re: more immediately relevant ideas, you could be right about a well-placed `Serial1.end()` and/or `Serial1.flush()` idea on the Boron side. On the OpenMV side, given that you're using `println()`, you might want `uart.readline()     # read a line` https://docs.openmv.io/library/pyb.UART.html

SUPScientist, 2024-06-21:
I bashed my head against the wall with a similar goal a few years ago. Thankfully I made a repo at that time and posted the code here: https://github.com/SUPScientist/CellpHOx/blob/master/10_CellpHOx_Vipul_PJBImproveTiming/src/10_CellpHOx_Vipul_PJBImproveTiming.ino.

In that case, I did a write and then a read on the Boron side (https://github.com/SUPScientist/CellpHOx/blob/77a79682f5c87aff60315a78a794554290044e75/10_CellpHOx_Vipul_PJBImproveTiming/src/10_CellpHOx_Vipul_PJBImproveTiming.ino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) whereas you're doing the reverse but it shouldn't matter much. There's nothing fancy in those couple relevant lines of code, but note the use of timeouts on the Boron side, which is buried in the way it listens to the peripheral sensor and waits a set amount of time for the response. Maybe the OpenMV has something similar.

efarq, 2024-06-25:
#commit 3a03ea4 . I believe I got this working. It was Serial1.print() for the boron, refreshing the serial1 in between, and uart.read() for the openmv

ebgoldstein, 2024-06-25:
Great work @efarq !!

Closed 2024-06-25.

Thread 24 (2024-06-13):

save images on openMV

ebgoldstein, 2024-06-13:
picture name images based on datetime and prediction

efarq, 2024-06-21:
Currently, code is saving images in a folder. However, the names are incorrect because I haven't gotten the datetime to work yet.

ebgoldstein, 2024-06-21:
nice. so this issue is linked to #23

efarq, 2024-06-25:
commit 3a03ea4

Closed 2024-06-25.

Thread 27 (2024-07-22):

Images stop saving / error in image aftert ~ 1 hr..

ebgoldstein, 2024-07-22:
This is from @efarq (in https://github.com/TinyCamML/Boron-and-OpenMV/issues/26#issuecomment-2243314197):

>Well, I just ran it successfully for one hour, and then the same issue started occurring. I have attached the datalog.txt, I have also attached the images, which shows that the same thing was happening with the images becoming a 2in1  situation. So I think I'll try adding the sensor.reset information in the while loop to see if that helps.

[images.zip](https://github.com/user-attachments/files/16336625/images.zip)
[DataLog.txt](https://github.com/user-attachments/files/16336617/DataLog.txt)

ebgoldstein, 2024-07-22:
ok, the last column of the datalog is the memory, which seems to stay constant/low..
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

this isuggests to me its not a memory issue, but maybe something else... what are th options on the table right now @efarq , @SUPScientist ?

ebgoldstein, 2024-07-22:
the glitches start at the pictures where the memory gets larger for a cycle or two...

SUPScientist, 2024-07-22:
Still curious about the info here (https://forums.openmv.io/t/sleep-mode-wakeup-with-external-interrupt/767/2), despite it being a bit old, as mentioned here (https://github.com/TinyCamML/Boron-and-OpenMV/issues/7#issuecomment-2236514945). The portion of the frame granted to the split image appears to grow over time which could be another symptom of lack of proper resetting?

SUPScientist, 2024-07-22:
Does sensor shutdown/sleep need to happen? I see those are commented out:

https://github.com/TinyCamML/Boron-and-OpenMV/blob/19091607839c727c075aa3a415274c732d4bae33/Firmware/OpenMV/PublishOpenMV.py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

efarq, 2024-07-22:
So I added the sensor.reset() lines to the while loop, and that still doesn't seem to fix the issue. The sensor shutdown items that are commented out are the steps that the senior design team took before putting their camera into machine.deepsleep(). I can try them for machine.sleep() though and see if it helps. The one other thing I think could be happening is when the boron sends its datetime to the openmv, the timing could be off, so then when the openmv tries to write that information to the logs, it doesn't have the number to do so and glitches or something

SUPScientist, 2024-07-22:
The main glitch here occurred before the addition of the `uart.read()` so I doubt it's that, but worth looking under every stone now I suppose.
https://github.com/TinyCamML/Boron-and-OpenMV/blob/19091607839c727c075aa3a415274c732d4bae33/Firmware/OpenMV/PublishOpenMV.py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

I don't understand how it was decided what goes into the while loop vs. not in the entire OpenMV script, though. What if almost everything is in that loop? @ebgoldstein, have a ref for what OpenMV does upon wakeup that might help us diagnose?

efarq, 2024-07-22:
Just tried adding the
    sensor.sleep(True)
    sensor.shutdown(True)
lines to the end before sensor.sleep() and that does not seem to work either.

ebgoldstein, 2024-07-22:
i see what you mean @SUPScientist - the whole camera might need to re-initialize in the `while` loop... the PR i link to above makes this change... @efarq , can you try it?

efarq, 2024-07-22:
Still does not work

ebgoldstein, 2024-07-22:
can you drop the txt file here?

efarq, 2024-07-22:
[DataLog.txt](https://github.com/user-attachments/files/16338034/DataLog.txt)
It looks like it did save the image and said "NoFLOOD" but did not send it over to the boron

efarq, 2024-07-22:
Ahh okay so the issue is not quite resolved. So it was just running nicely for about 40 minutes and then started doing the thing again. The only difference from when Evan and I were looking at it successfully on zoom until now was that I put the sampling period back to 6 minutes and turned the publishing back on for the Boron. On the OpenMV, the images look fine, but a new ERROR.txt was created, which I've attached. Also, the OpenMV light started blinking nonstop, which is what caught my eye this time, which hasn't happened really much before

https://github.com/user-attachments/assets/c70c18a1-6da7-4265-9d93-b6eef2ce623c

[DataLog.txt](https://github.com/user-attachments/files/16339282/DataLog.txt)
[ERROR.LOG](https://github.com/user-attachments/files/16339283/ERROR.LOG)

ebgoldstein, 2024-07-22:
shoot.. ok, looking at forums now...

ebgoldstein, 2024-07-22:
can you try something simple, and just replace the jpg to bmp on this line:

https://github.com/TinyCamML/Boron-and-OpenMV/blob/19091607839c727c075aa3a415274c732d4bae33/Firmware/OpenMV/PublishOpenMV.py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

so  `img.save("./images/" + file_name + ".bmp") `

(this error has popped up previously on the forums related to jpg stuff...

ebgoldstein, 2024-07-23:
ok, @efarq - can you change back to jpg, run the code till it breaks, and post all of the relevant details here (the exact OpenMV code, the folder of images, datalog, and error log)? and also maybe any details (how long it has run for)?

i think its time we post on the OpenMV forums, and I can do that

ebgoldstein, 2024-07-23:
also, please note the firmware, and openMV details (at the bottom of the IDE)

efarq, 2024-07-23:
Exact openmv code:
folder of images:
datalog file:
error log:
Firmware:
Board:
Things we've tried: changing .jpg to .bmp, adding a gc.collect(), adding del img, making sure we have the sensor.shutdown and reinitializing the camera after every restart

Also, I have a question for @SUPScientist, the openmv issue seemed to be fixed until we turned on the cellular from the boron and entered the publish state. In the publish state, we have the following lines of code:
   ` // Clean out any residual junk in buffer and restart serial port
    Serial1.end();
    delay(1000);
    Serial1.begin(9600);
    delay(500);
    Serial1.setTimeout(TIMEOUT_TINYCAM_MS);`

    My question is why do we begin the Serial1 again when we don't use it for the rest of the publish or sleep state? Could that be causing a mismatch between the boron and openmv?

ebgoldstein, 2024-07-23:
just to clarify @efarq - if cellular is off, the OpenMV will run forever?

efarq, 2024-07-23:
I only saw what we saw on zoom together yesterday but it looked like it was working great without cellular. I'll try it out again real quick

SUPScientist, 2024-07-23:
OK, interesting. Eager to hear results of next test with publishing off (`#define PUBLISHING 0`). No idea how/when/from whom that chunk
https://github.com/TinyCamML/Boron-and-OpenMV/blob/19091607839c727c075aa3a415274c732d4bae33/Firmware/Boron/src/TinyCamPublish.ino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
crept into `PUBLISH_STATE` but you're correct that it doesn't make sense there. Good catch.

ebgoldstein, 2024-07-23:
We need a very minimal reproducible example of the failure if we are going to post on OpenMV forum, so i am trying this (with firmware 4.5.5):

Note that there is no `sleep` (nor `poll`, nor `uart.read`), but each loop it re-initializes then shuts down the camera...

```

import sensor, image, time, utime, pyb, tf, machine, gc, os, uselect
from pyb import UART, Pin, ExtInt
from machine import LED

uart = UART(1, 9600) # UART1, adjust baudrate as needed

net = tf.load('MNv2Flood_cat_CG.tflite', load_to_fb=True)
labels = ['Flood', 'NoFlood']

#make directory to save images
if not "images" in os.listdir():
    os.mkdir("images")  # Make a directory

pin = Pin("P7", Pin.IN, Pin.PULL_UP)
ext = ExtInt(pin, ExtInt.IRQ_FALLING, Pin.PULL_UP, callback)

curr_time = 0
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
ebgoldstein, 2024-07-23:
@efarq - I have read that sometimes long openMV runs where it's connected to the IDE have problems. Is it possible for you to try deploying this not connected to the computer and see what happens?

efarq, 2024-07-23:
Currently, the only thing connected to my computer is the boron, which is powering the rest of it - so the OpenMV is not connected to the IDE.

Just writing down this idea - but maybe the next best thing to do would be make some sort code that runs like:
1. Boron wakes up OpenMV and waits to move on until it receives something from Serial1.readString() aka flood or no flood.
2. The openmv has a delay while the serial1 is resetting in the boron and then waits to move on until it receives a value for the datetime from the boron. Then it sends an "all clear" to boron
3. Then the Boron won't enter publish mode and subsequently publish mode until it receives an "all clear"

I guess that opens the possibility of either one getting stuck in infinite loops but just thinking about how to get their timing lined up. The other thing I am wondering about is if there is a way to turn off the vusb power entirely on the boron each cycle, as that would give the openmv a fresh start every time. Because we use the A0 pin on the boron to toggle the openmv on, it seems like you may have thought about that before. Perhaps machine.lightsleep() doesn't reset the camera enough? Just brainstorming at this point

ebgoldstein, 2024-07-23:
i like this idea, especially if we pair it with writing to a text file on OpenMV to help debug...

ebgoldstein, 2024-07-23:
and i think we need this sort of brainstorming... i firmly believe there must be a way forward, and i think it involves being more careful with all the comms (and having a way to track it for debugging)..

SUPScientist, 2024-07-23:
> The other thing I am wondering about is if there is a way to turn off the vusb power entirely on the boron each cycle, as that would give the openmv a fresh start every time.

This merits more exploration. A FET switch tied to VUSB's output from Boron to OpenMV and another GPIO on Boron should do the trick (should have some in the lab, same as I think you used for SEACOWs). The "fresh start" idea is compelling.

Re: @efarq's other idea that slows down/makes more explicit the Boron<—>OpenMV handshake seems reasonable but I'm having a hard time guessing how that gets at the root problem here. Maybe serial.flush statements on both sides "clean out" any residual stuff in buffers if that's the hypothesized problem?

efarq, 2024-07-23:
I will continue to investigate this week...

efarq, 2024-07-30:
I saw @ebgoldstein's branch about cleaning up the uart communications and that it worked for you for at least one hour. Were you testing that with cellular on the boron? Your code is not quite working as nicely for me.

However, last week I did add the mosfet switch into the system and it seems to work great! I ran it for almost 12 hours with no issues except that it adds a � into the result, which I cannot figure out how to get rid of:
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

It does seem to publish the character with no issues though so I don't think the character is necessarily a huge issue but will just need to be fixed eventually. Here is the code within the branch that adds the on/off switch:
https://github.com/TinyCamML/Boron-and-OpenMV/blob/OpenMVFix/Firmware/Boron/src/TinyCamPublish.ino

I'll test it again today but I feel pretty good about the consistency with the mosfet switch.

ebgoldstein, 2024-07-31:
this is great news @efarq !

Did your second test run ok?

if so, i guess the action item is to make sure the boron & OpenMV are exactly the same as one the decives.. ( i see the new circuit diagram w/ mosfet).. then close the issue and we all have a big party in your honor for figuring it out!

efarq, 2024-08-01:
Yes the second test seemed to run quite nicely! So maybe the mosfet switch is the way to go. What do you mean by, "the action item is to make sure the boron & OpenMV are exactly the same as one the decives" before closing the issue?

ebgoldstein, 2024-08-01:
Sorry, was not super clear.. All I mean is- 'If the code on GitHub the exact same as the code on the devices, close the issue. If not, update code and close the issue'

efarq, 2024-08-01:
Perfect, just wanted to make sure before I changed anything! Here is the merge: commit b141d4c

Closed 2024-08-01.

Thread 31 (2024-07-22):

Add new stl files

ebgoldstein, 2024-07-22:
antenna, baseplate, bracket, etc... just check to make sure they are all the most up to date versions

jacobstasiewicz, 2024-07-22:
up to date on stl files, will update form file soon

jacobstasiewicz, 2024-07-23:
updated

Closed 2024-07-23.

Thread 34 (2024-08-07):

Carrier Board / PCB for Boron and OpenMV

ebgoldstein, 2024-08-07:
Current status:
- Thanks to hard work from @efarq , we now have a stable prototype some new bits of hardware (i.e., a MOSFET - thanks for the suggestion @SUPScientist !). The wiring, microcontrollers, and cell antenna fit in the polycase, and are mounted using 3D printed parts (thanks @jacobstasiewicz ).

In the future, it would simplify future builds if there was a manufactured PCB where the electronic parts were pre-populated on the board, and the microcontrollers could just plug into headers. to do this we would likely need:

- A PCB design that accounts for the microcontroillers and the electronic components (see the circuit diagram)
- new 3d printed parts that attach the PCB to the polycase

mjsaenz, 2024-12-17:
Hi everyone! I am Matthew Saenz. I am a master's student in Electrical and Computer Engineering at Carnegie Mellon University and an intern at the Field Research Facility in Duck, NC. Evan has brought me on to work on this task, as well as investigating the solar power supply.
I'd like to begin with listing high level system requirements I derived from my discussion of the project with @ebgoldstein this morning:

1. The PCB shall have mounting locations for all devices in the circuit diagram, i.e. the Boron board, the OpenMV board, the MOSFET, and the voltage divider resistor.
2. The PCB shall connect the devices as specified in the circuit diagram via circuit traces.
3. The PCB shall not displace the antenna mount location, but may modify the other mounting hardware as necessary.
4. The PCB shall include a mounting location for a screwhead terminal or similar to enable testing alternative power supplies.
5. The USB and SIM card ports of the Boron board shall be easily accessible in the fully assembled configuration.
6. The SD card port of the OpenMV board shall be easily accessible in the full assembled configuration.

Regarding the placement of the PCB, would it be better to mount it on top of the Boron and OpenMV, or below them? I am currently leaning towards below the boards, as it would enable a simpler form factor for the PCB reducing manufacturing costs, but in the baseplate assembly drawing, the header pins appear to be oriented upward from the boards.

Please let me know if you have any feedback on these design requirements, as well as if there are any other desired features of the PCB.

SUPScientist, 2024-12-17:
Great to meet you, Matthew, and welcome to the team :) In case @efarq doesn't have automatic notifications, I'm tagging her here explicitly as she has spent the most time of any of us with hands on the device. @efarq, maybe you could share your google slide deck with @mjsaenz as well as it has some helpful photos (while you're at it, could you add a couple of those to the assets folder here?

Responding to your system requirements below where there's anything to add. If I haven't added anything, then I agree!

1. The PCB shall have mounting locations for all devices in the circuit diagram, i.e. the Boron board, the OpenMV board, the MOSFET, and the voltage divider resistor. *PJB response: we haven't been able to use the voltage divider for meaningful voltage monitoring. @efarq please confirm but I recommend removing unless we anticipate future usability. FET switch (with its resistor definitely stay.*
2. The PCB shall connect the devices as specified in the circuit diagram via circuit traces.
3. The PCB shall not displace the antenna mount location, but may modify the other mounting hardware as necessary. *PJB response: please see https://docs.particle.io/hardware/certification/antenna/#cellular-antenna-dimensions for antenna spec. @jacobstasiewicz please confirm that current antenna mount meets spec.*
4. The PCB shall include a mounting location for a screwhead terminal or similar to enable testing alternative power supplies.
5. The USB and SIM card ports of the Boron board shall be easily accessible in the fully assembled configuration. *PJB response: Boron uses a soldered on eSIM so access is not required.*
6. The SD card port of the OpenMV board shall be easily accessible in the full assembled configuration.

Regarding the placement of the PCB, would it be better to mount it on top of the Boron and OpenMV, or below them? I am currently leaning towards below the boards, as it would enable a simpler form factor for the PCB reducing manufacturing costs, but in the baseplate assembly drawing, the header pins appear to be oriented upward from the boards.
*PJB response: Boron has male header pins pointing downward (such that your carrier PCB should be underneath Boron with female headers/sockets). I thought this was also the case for OpenMV but a recent photo from @efarq shows the opposite, so we need her confirmation.*

Other desired features. *PJB response: the current connector that accepts the solar panel cable's plug and converts it to micro-USB (this: https://voltaicsystems.com/A101/) is a little clunky in my opinion, but it works. Would like @efarq's opinion here also (if it ain't broke, don't fix it?) but the power jack socket on this board (https://github.com/iorodeo/iorodeo_feather_tripler_enc1) that then runs the 5V trace to the Boron's VUSB input could also work. Researcher needs to remember to unplug solar before using USB cable from computer or vice versa.*

ebgoldstein, 2024-12-18:
Hi @mjsaenz , thx for the list.

@SUPScientist - this morning @mjsaenz and I had a call to discuss these issues, and he is connected to @efarq via email to get an actual device. Jacob is away for the week, but the antenna works so my opinion is that we not mess with the configuration.

the carrier board should attach from below. I can confirm via a phone call w/ @efarq that the OpenMV @mjsaenz will get has downward facing male headers.

Power:
- I spoke to @mjsaenz about power, and trying to estimate power budget, which we have discussed in variou issues: #1, #9, #10, #43, and #45 .
- I mentioned that the voltaic panel and battery we are sending over is regulated, and will not output meaningful numbers for power budget estimation.
- I mentioned that Particle boards expose a way to monitor battery voltage from a LiPo via the C++ API (https://docs.particle.io/reference/device-os/api/fuelgauge/getvcell/), so we are interested in working with a new battery that could integrate with this ability.
- I mentioned that we want to future proof this PCB by allowing for other battery and solar panel solutions to be connected, and monitored (so using ones that are not regulated). This might necessitate adding or retaining things on the PCB (voltage divider, screw terminals, etc).
- the power management stuff is definitely a 'stretch goal', so my opinion is that we ask @mjsaenz to focus first on just building the basic PCB, and then if he has time tackle some of the power stuff.

how does this sound?

SUPScientist, 2024-12-18:
Nope, shouldn't mess with the antenna holder itself, agreed. The important spec to bear in mind for PCB design is this:
> All portions of the antenna should maintain proper spacing from electronics, grounded metal, or active metal.
Recommended: 12mm
Minimum: 8mm

I didn't mean we should mess with antenna holder, just that we should maintain minimum distance between antenna and other electronics.

As for monitoring battery voltage, what we do on the water level sensors is (1) use the same Voltaic panel/battery as TinyCamML and (2) also use a small LiPo inside the polycase and the code:
`// Get battery charge
    float cellVoltage = batteryMonitor.getVCell();
    float stateOfCharge = batteryMonitor.getSoC();`

ebgoldstein, 2024-12-18:
so there are two batteries - the voltaic one and then a smaller LiPo? is the idea that the small battery is just extra, and will better reflect the state of the charge for the both batteries?

efarq, 2024-12-18:
Hi all,

I have indeed shared the TinyCamML google drive with Matthew, so let me
know if you don't receive it. Also, I realized the current configuration of
the OpenMV has the female headers facing down (opposite of what I told you,
Evan). However, this could be easily changed for all future TinyCamMLs, as
each OpenMV comes with male headers that can be soldered on instead of the
female ones.
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
ebgoldstein, 2025-01-06:
this looks appropriate and good to me, but I'm interested to hear from @efarq and @SUPScientist ..

SUPScientist, 2025-01-07:
Thanks, @mjsaenz. We have a few modification requests, sketched up and described below.

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

Please add to the PCB the following:
1. J1: Female socket/barrel plug connector to accept the plug from the voltaic battery pack (voltaic's output is Male 3.5 x 1.1mm output cable: https://voltaicsystems.com/5-watt-5-volt-35wh-solar-system/).
2. SW1: On/off switch immediately after J1.
3. Short VUSB on Boron, VIN on OpenMV, and output of switch SW1 (all 5V).
4. Female header pins to accept Boron and OpenMV and necessary traces as indicated (e.g., Rx/Tx to P1/P0)
5. FET as shown with appropriate traces.

Note I added the GND nets to indicate shared ground between output of the voltaic battery pack and Boron. OpenMV is only grounded when FET switch utilized thus controlling its power.

This sound right, @ebgoldstein @efarq? Thanks!

mjsaenz, 2025-01-07:
@SUPScientist Understood, I will send an updated board schematic soon. To confirm. we are no longer interested in pursuing alternative power supplies via a screw terminal?

SUPScientist, 2025-01-07:
Thank you! Confirmed (assuming you can readily find the proper mating female barrel plug connector which will serve that same purpose).

mjsaenz, 2025-01-07:
My branch can be found here: https://github.com/TinyCamML/TinyCamML/tree/PCB

SUPScientist, 2025-01-07:
Wow, that was fast, thanks! Looks great! And as @ebgoldstein nicely stated earlier, thanks for putting up with our evolving whims.

I think it's good to go and I have no requested changes, just gonna jot a couple notes to make sure we're all on the same page.

@efarq, are you good with orientation of Boron & OpenMV? This shows micro-USB connector facing bottom of board on Boron, camera facing top of board on OpenMV with its micro-USB connector on bottom of board. Seems good to me and mirrors recent photos of your setup but your confirmation would help.

The male barrel plug comes into the connector from the right edge, correct? @efarq, please confirm you're good with that rotation. That might make for a tight fit against the right edge of the PolyCase. Would the plug entering from the bottom edge upwards (i.e., female barrel connector facing down) make for an easier connection?

Finally, to be explicit, I want to write out the function of S1 and confirm I'm understanding. Is this correct?
VUSB (Boron) and VIN (OpenMV) are shorted regardless of switch position.
- With switch in **ON** position, barrel plug's voltage is also connected to VUSB and VIN (i.e., powering both boards).
- With switch in **OFF** position, barrel plug's voltage is disconnected from rest of circuit.

mjsaenz, 2025-01-07:
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

That is correct.

I also realized that I forgot to specify the units in the board diagram. below is an updated diagram with the units:
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

The through-holes on the board are designed to fit M3 screws for mounting within the PolyCase.

efarq, 2025-01-10:
Looks great! Sorry for delayed response (fieldwork), but I think the orientation of the openmv and boron looks great! However, I think the barrel plug and the switch should swap places because we need to be able to access the microsd card on that side of the openmv easily, and its current location is blocking it. I think the barrel plug is fine to continue facing towards the right, since the cable gland is on that side and the cable only needs to go straight from the cable gland to plug in.

mjsaenz, 2025-01-10:
@efarq Understood! I have swapped the locations of the switch and barrel jack to allow easier access to the SD card slot.
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

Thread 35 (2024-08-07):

new way to deal with TF in OpenMV

ebgoldstein, 2024-08-07:
the new openMV firmware has some breaking changes for how it deals with ML models:

https://openmv.io/blogs/news/giant-tensorflow-update

efarq, 2025-07-10:
I've got a pretty good start on this as seen in commit cffa386 . However, I think @ebgoldstein should check to make sure I have correctly designated the first and second elements of the TF_objs list to Flood and No Flood, respectively, and everything else makes sense. Additionally, I have noticed that the memory allocation (which previously ran around 9300) is now running at 2594064 with this new version, so any tips you may know of for decreasing that would be helpful.

ebgoldstein, 2025-07-14:
I think that is correct re: the TF_objs.
I think we need to run the code on teh device as a test re: the memory, to see if it fails at some point when being deployed..

efarq, 2025-07-29:
Just wanted to follow up that I ran the new ML code for 12 days on a TinyCamML and it did indeed capture the expected ~240 images and outputs for each day. It looks like it might have missed publishing a couple times, which is probably more of a Boron/service issue than an OpenMV issue, since everything was logged. Continuing to look into it.

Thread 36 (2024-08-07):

Assess how physical housing stands up to elements

ebgoldstein, 2024-08-07:
after deployment, we should evaluate this.

ebgoldstein, 2024-09-24:
@efarq - any insight you want to add here? or should this issue be closed because things are working fine so far

efarq, 2024-09-27:
Hi,
I think we can close this until something specific comes up! It seems like everything looked pretty good to me from the last deployment, although I have the follow notes:

- salt was crusted along the battery, so we should make sure we always put o-ring grease plentifully on the o-ring of the battery (and the polycases')
- the 3D printed parts seemed totally fine from this short deployment, but I'll be interested to see how they do with long-term UV exposure
- the polycase did tilt down overtime (causing the images to get more and more downward facing), suggesting that either I need to tighten the tilt screw harder during deployments, or if it's a continued issue, change the design a bit
- any hardware that wasn't stainless steel rusted
- we'll see how trusty these plastic cable glands are long-term - so far, so good

Closed 2024-09-27.

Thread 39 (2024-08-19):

Add CAD files for all 3d printed parts

ebgoldstein, 2024-08-19:
can be in a separate `/CAD/` folder in `hardware/3D_Printed_Parts/`

jacobstasiewicz, 2024-08-20:
Uploaded, closing now

Closed 2024-08-20.

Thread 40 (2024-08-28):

Get rid of the diamond with question mark

efarq, 2024-08-28:
When the OpenMV sends over "Flood" or "NoFlood" to the Boron, it also includes a diamond with a question mark. According to forums, it seems like a utf-8 decoding error, but I have tried getting rid of it to no avail. Since it wasn't occurring before I added the MOSFET switch, I'm wondering if it'll go away when we potentially get rid of the voltage divider. I mostly just wanted to put this in here so I don't forget about it.

Also, I labeled it as an enhancement instead of a bug since everything still works with the diamond question mark.

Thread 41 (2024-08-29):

TooDark as an option (not just flood/noFlood

ebgoldstein, 2024-08-29:
psuedocode to do this would be:

```

# Set the threshold for detecting dark images
brightness_threshold = 10  # Adjust this value as needed

while True:
    img = sensor.snapshot()

    # Calculate the average brightness of the image
    avg_brightness = img.get_statistics().mean()

    # Check if the image is too dark
    if avg_brightness > brightness_threshold:
        # TF image and send Flood or NoFlood
    else:
        #send 'tooDark to Boron

```

ebgoldstein, 2024-10-07:
@efarq , I'm interested in integrating this in the OpenMV code...
so it would be something like this:

```
# Set the threshold for detecting dark images
brightness_threshold = 10  # Adjust this value as needed
```

```
while(True):
    #Reinitialize the sensor after sleep
    sensor.reset() # Initialize the camera sensor.
    sensor.set_pixformat(sensor.RGB565)
    sensor.set_framesize(sensor.QVGA)
    sensor.skip_frames(time = 2000)

    #TAKE PIC
    img = sensor.snapshot()

    # Calculate the average brightness of the image
    avg_brightness = img.get_statistics().mean()

    # Check if the image is too dark. if not, classify
    if avg_brightness > brightness_threshold:
        TF_objs = net.classify(img)
        Flood = TF_objs[0].output()[0]
        NoFlood = TF_objs[0].output()[1]
        if Flood > NoFlood:
            #print('Flood')
            uart.write('Flood.')
            pyb.delay(1500)
            floodstate = "Flood"
        else:
            #print('No Flood')
            uart.write('No Flood.')
            pyb.delay(1500)
            floodstate = "NoFlood"

    else:
        #print('Too Dark')
        uart.write('Too Dark.')
        pyb.delay(1500)
        floodstate = "TooDark"

    print(floodstate)
```

would this break the Particle code? if you think its good, do you want me to push changes?

ebgoldstein, 2024-10-09:
i committed the change, via https://github.com/TinyCamML/Boron-and-OpenMV/commit/e52709d024e355e2a98bf9cb9b583711de385b0d

Closed 2024-10-09.

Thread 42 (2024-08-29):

different repository for analysis codes?

ebgoldstein, 2024-08-29:
All,
do we want to put analysis codes in a different repository? [I started one and put my notebook from today in there](https://github.com/TinyCamML/DeploymentAnalysis)

ebgoldstein, 2024-08-29:
(I see you code @SUPScientist - and i tried not to be duplicative (i.e., i did not add any met/ocean data yet)

SUPScientist, 2024-08-29:
Happy to follow your lead—this works for me! Should I move (or feel free to do so yourself) mine over to the new repo, then?

anardek, 2024-08-31:
It doesn’t matter to me as long as there are no links to the photo storage.

On Thu, Aug 29, 2024 at 5:15 PM Phil Bresnahan ***@***.***>
wrote:

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

ebgoldstein, 2024-09-24:
done

Closed 2024-09-24.

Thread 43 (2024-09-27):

New battery that allows monitoring

SUPScientist, 2024-09-27:
### Problem
As described also in https://github.com/TinyCamML/Boron-and-OpenMV/issues/9, the Voltaic battery pack is regulated and cannot be meaningfully monitored. Confirmed by Voltaic in exchange with @efarq.

### Recommended Solution
Find another rechargeable battery pack that meets Boron/OpenMV power requirements (and max voltages) but which can be monitored.

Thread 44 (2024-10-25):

openmv won't save > 1024 images with certain micro-SD cards

SUPScientist, 2024-10-25:
### Observed behavior
@efarq writes in email "TinyCamMLs Maiden voyage" on 23-Oct-24: "So TinyCamML2,3, and 5 stopped saving images once they hit about 1000 images saved (which was like yesterday) but did keep recording in their datalog. I reset the tinycammls so they are still out there running currently and I’ll probably check on them Friday. TinyCamML1 seems to be totally fine, which is interesting because it is the only one whose sd card is different (picture below) and it has the voltage divider. All of the sd card formats are the same, so I’m thinking this sounds like some sort of specific sd card bug? I’m going to mess around with the extra TinyCamML and see if I can recreate it but let me know if y’all have any ideas."

### Expected behavior
TinyCamMLs keep saving images as long as there is available space on micro-SD card

SUPScientist, 2024-10-25:
This thread and in particular [this comment](https://forums.openmv.io/t/consuming-time-issue-of-saving-image-to-sd-card/5815/2) suggests using `ImageWriter` rather than `save`. `save` evidently spends time finding open space on the SD card that increases as more space is filled up, maybe getting to the point that the save operation isn't completing when the device goes to sleep.

Another quick band-aid solution could be to add a delay or query the result of
https://github.com/TinyCamML/Boron-and-OpenMV/blob/bcfeacb64a2c065acb4354f63079edc074f35b6f/Firmware/OpenMV/PublishOpenMV.py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
and have a blocking loop below it that doesn't let you proceed (and go to sleep) until it responds. I don't know if the `save` method returns anything, but that's worth looking into also.

Lots of forum posts about seemingly related issues! https://forums.openmv.io/t/saving-stream-of-jpeg-images-to-sd-card/1648

ebgoldstein, 2024-10-25:
imagewriter is deprecated, so it would be image.ImageIO . this would essentially save a video file, that we would decode later.. this is not that fun, so i suggest a possible hack: new directories every day

so before the while loop:

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

and in teh loop:

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

efarq, 2024-10-30:
Just wanted to let y'all know I am currently testing this out right now and I think its working. I'm going to let it run for a few days at home before I commit the code, but basically I added a one second delay before turning off the OpenMV in the Boron's code, and then in the OpenMV code, I added this function definition, using the Boron's timestamp as the basis:

`def get_today_folder():
    ts = int(curr_time) #time from boron
    tsdt = list(time.localtime(ts)) #convert from tuple to list
    tsdt[0] = (int(tsdt[0])-30) #subtract 30 years bc micropython starts timestamps at 2000
    date_str = f"{tsdt[0]}-{tsdt[1]}-{tsdt[2]}" #extract date
    folder_path = f"{date_str}"
    if not folder_path in os.listdir():
        os.mkdir(folder_path)
    return folder_path
`
and at the bottom:
`today_folder = get_today_folder()

    with open("./DataLog.txt", 'a') as file:
        file.write(curr_time + "," + floodstate + "," + str(gc.mem_alloc()) + "\n")

 img.save("./" + today_folder + "/" + file_name + ".jpg")`

Closed 2025-01-13.

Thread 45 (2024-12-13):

External battery dies in the cold night and doesn't turn back on until it's warm enough

efarq, 2024-12-13:
Since we've been having colder weather, I've noticed that on some TinyCamMLs, the battery dies in middle of the night and then won't come back on until later in the day when it's warmed up/gotten a chance to recharge. This means the TinyCamML could miss capturing any morning floods. Maybe we could try some type of insulating sleeve on the batteries?

ebgoldstein, 2024-12-13:
I think also we could sleep longer if the openMV reports it's too dark and it's between some specific hours of the day. This could be a simple look up table on the boron based on sunrise/sunset.

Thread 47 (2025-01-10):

make PCBs

ebgoldstein, 2025-01-10:
- [ ] get PCBs
- [ ] get componenets
- [ ] manufacture
- [ ] test

efarq, 2025-02-02:
So I was just about to test the PCBs, but I ran into one small issue. The measurement for the OpenMV pins is off by a maybe 1 mm or so, so it is not possible to simply plug in the OpenMV. Photos attached.

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

ebgoldstein, 2025-02-03:
@mjsaenz - is this is a quick fix that you do you think?

mjsaenz, 2025-02-03:
> [@mjsaenz](https://github.com/mjsaenz) - is this is a quick fix that you do you think?

Hey Evan,
It should be a quick fix. My apologies for this mistake. The schematic on OpenMV website did not have the distance denoted on it, so I had to use the ruler on the CAD model viewer. It looks like the "object to object" option I used measured closest point to closest point, giving me the original 30.78mm distance. Remeasuring with "point to point" shows a distance of 32.26mm center to center. I will update the model and upload it to the repo tonight.

ebgoldstein, 2025-02-03:
No worries at all @mjsaenz !!

ebgoldstein, 2025-02-03:
I just verified that distance with my calipers on an OpenMV. @efarq - do you have calipers handy to verify that measure on your end?

mjsaenz, 2025-02-04:
Hi all,
I have updated the board layout to the proper distance between the OpenMV pins here: 3b9fc03c831bb1989981e911a0714abf54d13449

ebgoldstein, 2025-02-04:
awesome- thx @mjsaenz - ordering next round of boards RN...

ebgoldstein, 2025-02-04:
@mjsaenz - Q for you: are the drill holes and board shape/size the same?

(I ask because @jacobstasiewicz could still design the 3D printed mount - (he has a v1 boards. )

mjsaenz, 2025-02-04:
> [@mjsaenz](https://github.com/mjsaenz) - Q for you: are the drill holes and board shape/size the same?
>
> (I ask because [@jacobstasiewicz](https://github.com/jacobstasiewicz) could still design the 3D printed mount - (he has a v1 boards. )

Yes. The only change is the position of the OpenMV pins.

ebgoldstein, 2025-03-24:
@efarq - have you deployed a TinyCamML with the new PCB? Are we ready to close this and order a few more boards?

efarq, 2025-03-27:
The TinyCamML with the new PCB ran successfully from 3/13/2025-3/27/2025 with no issues. Therefore, I think we are ready to close this and order some more boards

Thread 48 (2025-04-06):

Internal Mount

jacobstasiewicz, 2025-04-06:
Hello All,

About a month ago I designed a baseplate for inside the case that incorporated the PCB. Before I finalized the design, I wanted to make sure the new PCB worked. Now that we know it is working, I have two questions mainly for Liz.

1. Can I see a picture of everything soldered on the PCB so I make sure I have orientations correct.
2. Before I finalize the new baseplate, I just wanted to double check that everything is in the general orientation it was before, and see if there was any comments/concerns mounting the old baseplate.

jacobstasiewicz, 2025-04-12:
Awesome thanks, just updated and printed a new test part. Everything fits and is snug. Like you said the pcb is larger than than the distance between the internal baseplate mount points so I assembled it in case. First put the antenna, and pcb 5mm standoffs on the baseplate, attach base plate incase, add pcb board and then add the openmv and boron.

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

This issue can be closed once some else confirms everything fits.

Closed 2025-06-23.

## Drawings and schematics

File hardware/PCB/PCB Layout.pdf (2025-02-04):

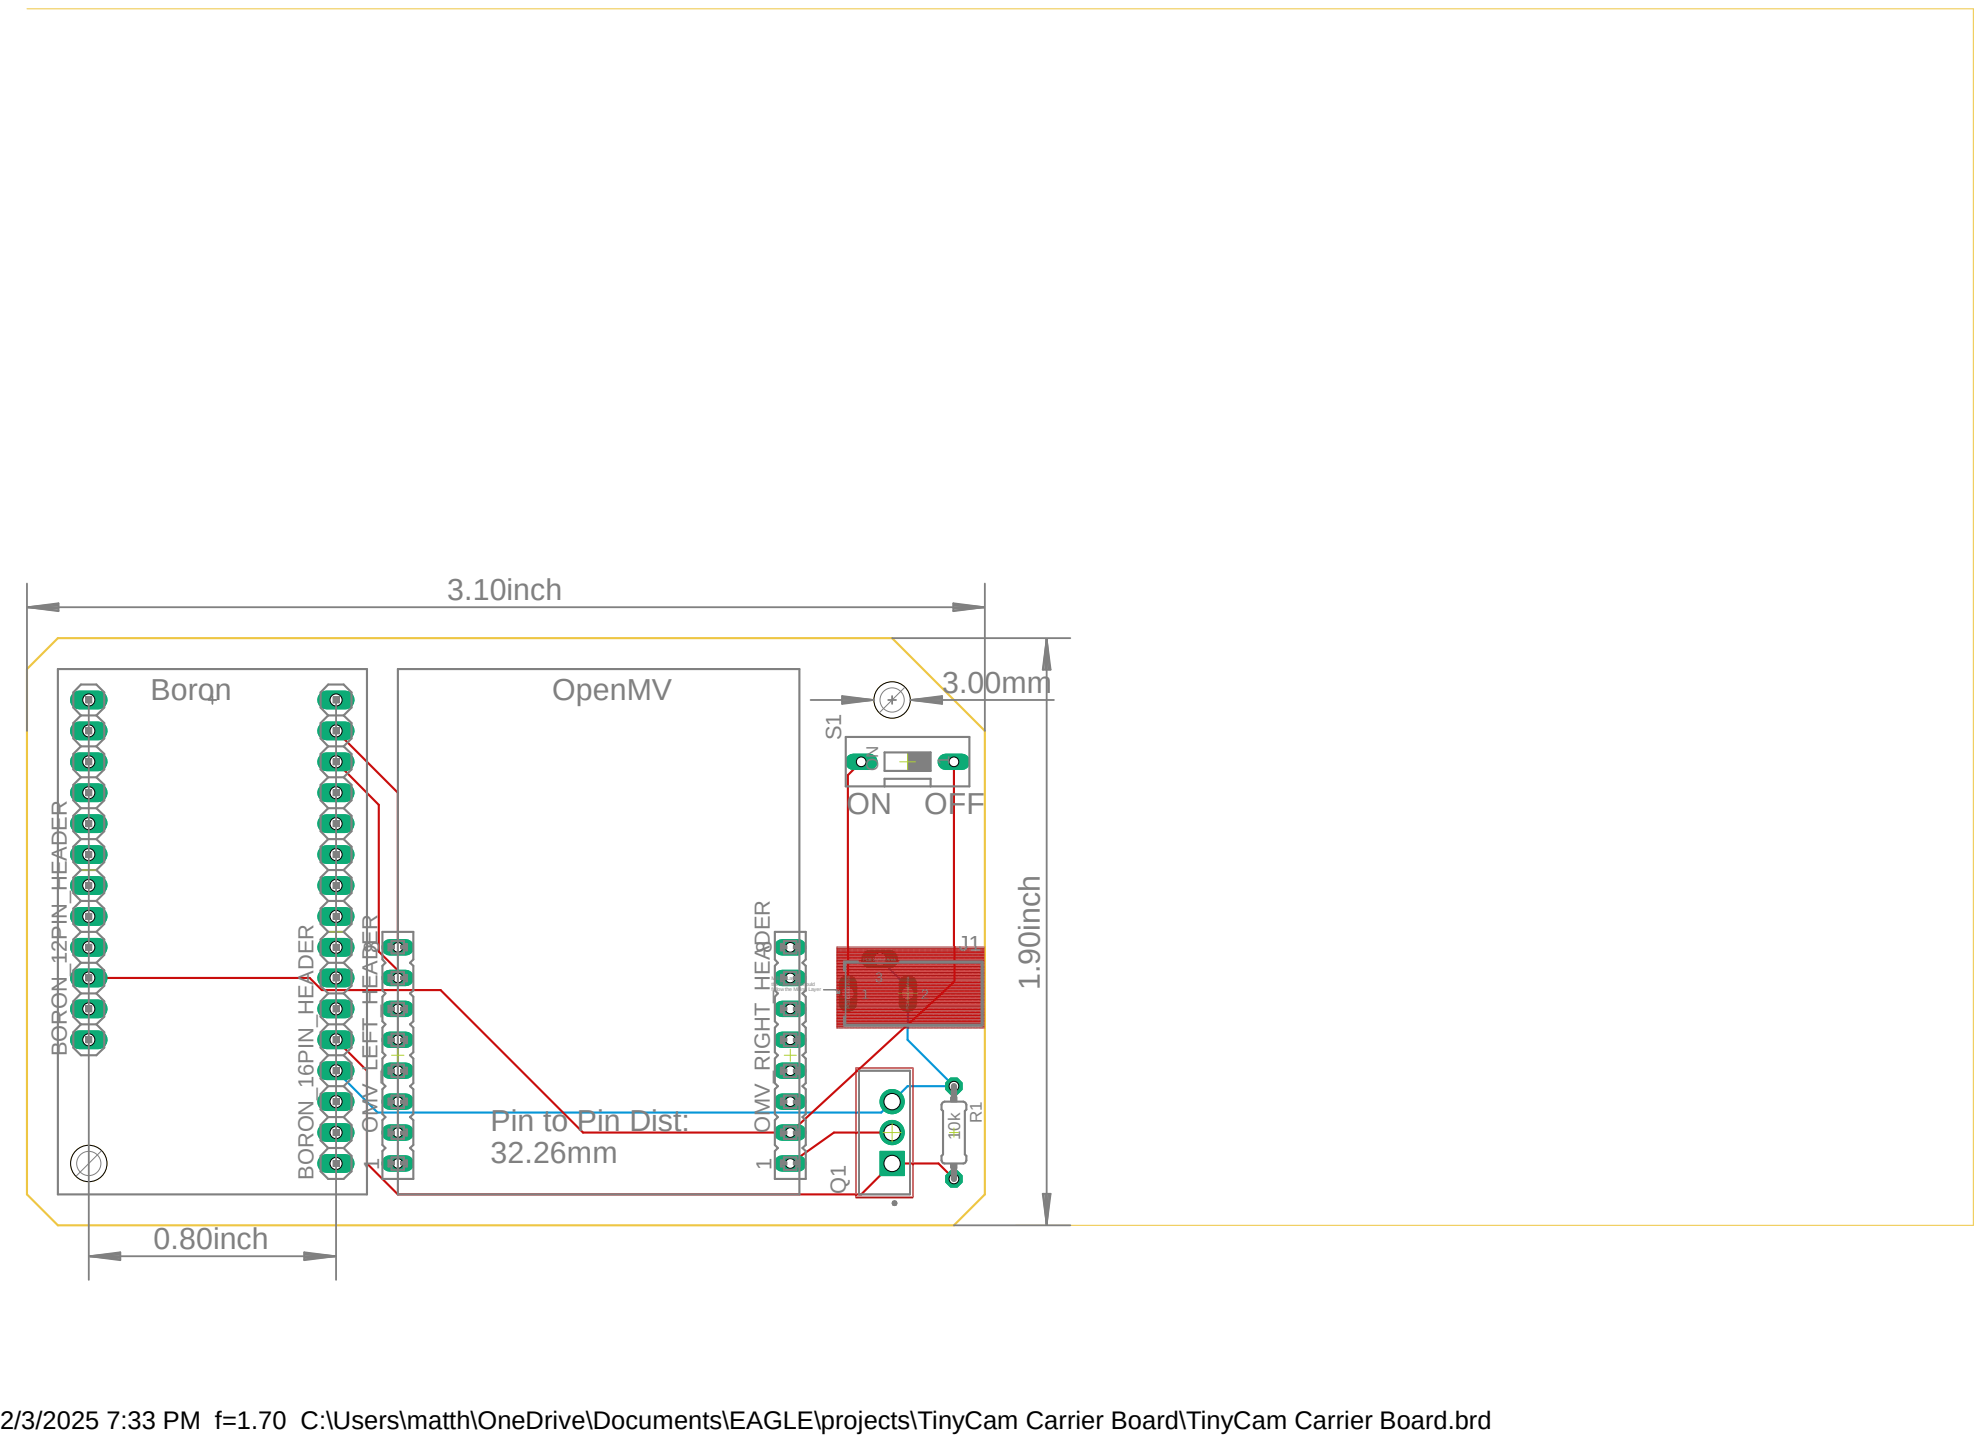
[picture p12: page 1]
Boron; OpenMV; 32.26mm BORON_16PIN_HEADER BORON_12PIN_HEADER; J1 OMV_LEFT_HEADER; OMV_RIGHT_HEADER; ON OFF10k; 0.80inch; 3.10inch; 1.90inch Milling Layer

the hole size should
follow the Milling Layer

Pin to Pin Dist:

2/3/2025 7:33 PM f=1.70 C:\Users\matth\OneDrive\Documents\EAGLE\projects\TinyCam Carrier Board\TinyCam Carrier Board.brd

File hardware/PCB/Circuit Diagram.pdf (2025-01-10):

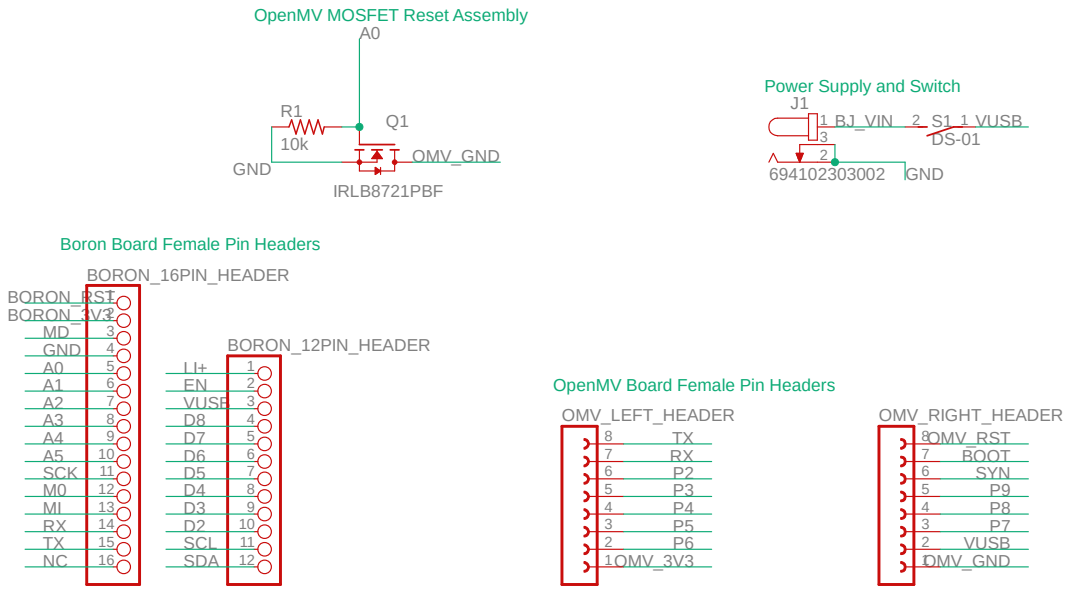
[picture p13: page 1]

OpenMV MOSFET Reset Assembly

OpenMV Board Female Pin Headers
8 OMV_LEFT_HEADER

Document Number: | REV:

Date: 1/7/2025 3:55 PM | Sheet: 1/1

1/7/2025 4:01 PM C:\Users\matth\OneDrive\Documents\EAGLE\projects\TinyCam Carrier Board\Board Schematic.sch (Sheet: 1/1)

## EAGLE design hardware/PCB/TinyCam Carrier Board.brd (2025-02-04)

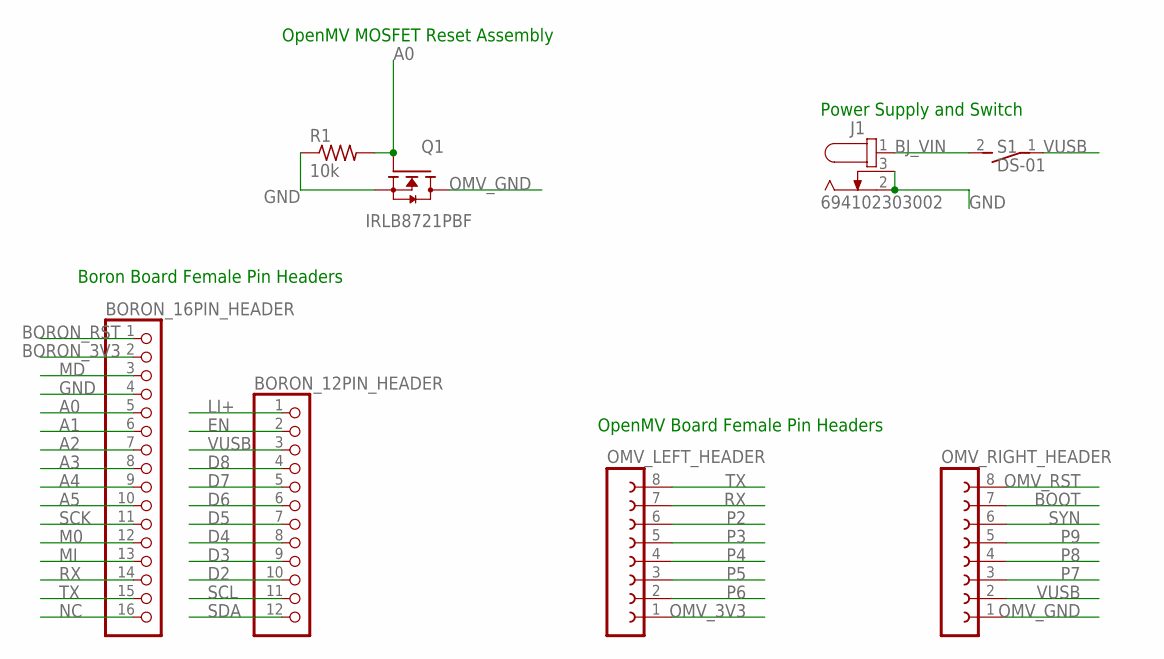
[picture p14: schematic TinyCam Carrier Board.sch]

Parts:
BORON_12PIN_HEADER: PINHD-1X12; 1X12
BORON_16PIN_HEADER: PINHD-1X16; 1X16
J1: 694102303002
OMV_LEFT_HEADER: FE08-1; FE08
OMV_RIGHT_HEADER: FE08-1; FE08
Q1: IRLB8721PBF; TO254P1067X483X2057-3
R1: 10k; 0204/7
S1: DS-01

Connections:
A0: BORON_16PIN_HEADER.5, Q1.1 (G), R1.2
A1: BORON_16PIN_HEADER.6
A2: BORON_16PIN_HEADER.7
A3: BORON_16PIN_HEADER.8
A4: BORON_16PIN_HEADER.9
A5: BORON_16PIN_HEADER.10
BJ_VIN: J1.1, S1.2
BOOT: OMV_RIGHT_HEADER.7
BORON_3V3: BORON_16PIN_HEADER.2
BORON_RST: BORON_16PIN_HEADER.1
D2: BORON_12PIN_HEADER.10
D3: BORON_12PIN_HEADER.9
D4: BORON_12PIN_HEADER.8
D5: BORON_12PIN_HEADER.7
D6: BORON_12PIN_HEADER.6
D7: BORON_12PIN_HEADER.5
D8: BORON_12PIN_HEADER.4
EN: BORON_12PIN_HEADER.2
GND: BORON_16PIN_HEADER.4, J1.2, J1.3, Q1.3 (S), R1.1
LI+: BORON_12PIN_HEADER.1
M0: BORON_16PIN_HEADER.12
MD: BORON_16PIN_HEADER.3
MI: BORON_16PIN_HEADER.13
NC: BORON_16PIN_HEADER.16
OMV_3V3: OMV_LEFT_HEADER.1
OMV_GND: OMV_RIGHT_HEADER.1, Q1.2 (D)
OMV_RST: OMV_RIGHT_HEADER.8
P2: OMV_LEFT_HEADER.6
P3: OMV_LEFT_HEADER.5
P4: OMV_LEFT_HEADER.4
P5: OMV_LEFT_HEADER.3
P6: OMV_LEFT_HEADER.2
P7: OMV_RIGHT_HEADER.3
P8: OMV_RIGHT_HEADER.4
P9: OMV_RIGHT_HEADER.5
RX: BORON_16PIN_HEADER.14, OMV_LEFT_HEADER.7
SCK: BORON_16PIN_HEADER.11
SCL: BORON_12PIN_HEADER.11
SDA: BORON_12PIN_HEADER.12
SYN: OMV_RIGHT_HEADER.6
TX: BORON_16PIN_HEADER.15, OMV_LEFT_HEADER.8
VUSB: BORON_12PIN_HEADER.3, OMV_RIGHT_HEADER.2, S1.1

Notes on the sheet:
Boron Board Female Pin Headers
OpenMV Board Female Pin Headers
OpenMV MOSFET Reset Assembly
Power Supply and Switch

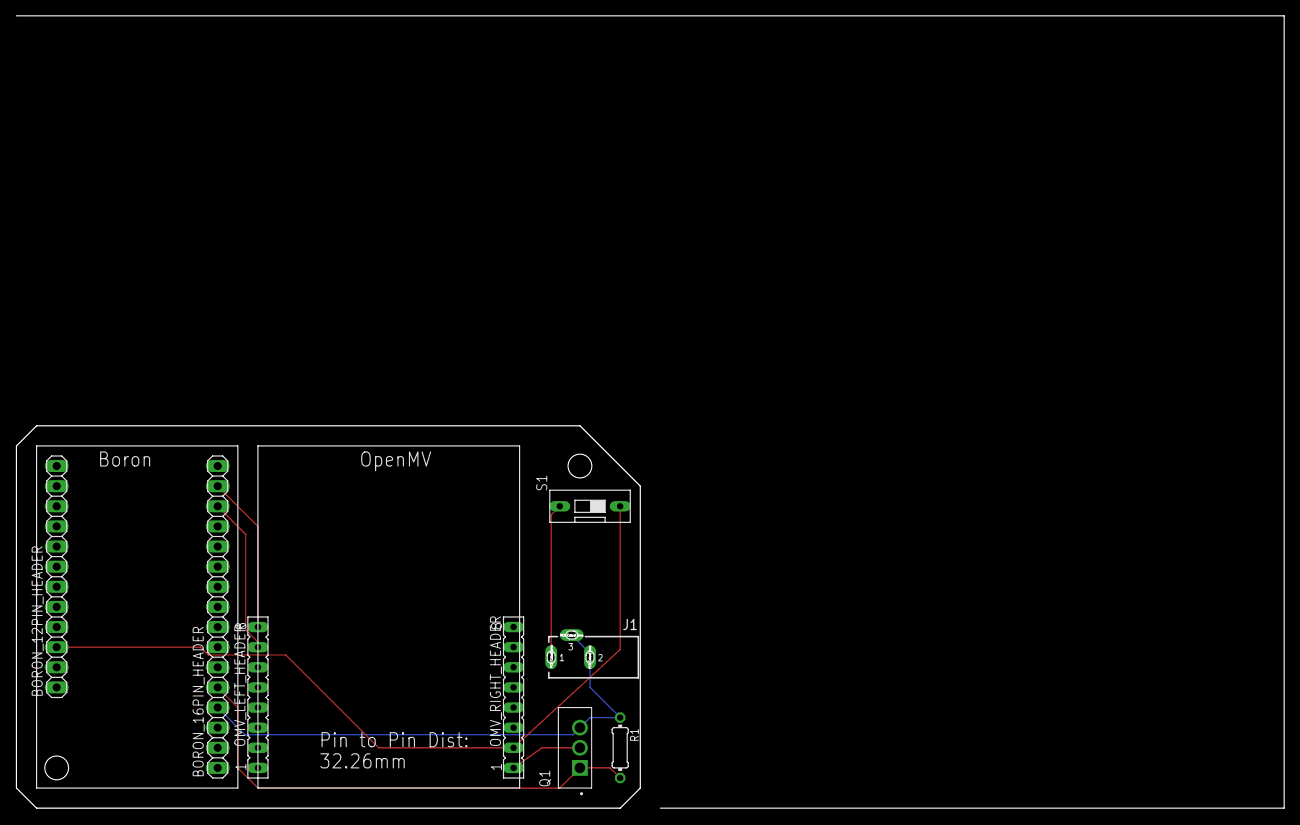
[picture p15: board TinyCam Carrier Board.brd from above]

Board: 2 copper layers, 78.7 x 48.3 mm, 8 parts (0 on the bottom side), 7 nets.

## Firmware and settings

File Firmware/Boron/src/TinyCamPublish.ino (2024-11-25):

//Include Particle Device OS APIs
#include "Particle.h"

long real_time;
int millis_now;

//------------------State variables
// not yet used but placeholders in case of additional states
enum State {
  DATALOG_STATE,
  PUBLISH_STATE,
  SLEEP_STATE
};
State state = DATALOG_STATE;

// Define whether (1) or not (0) to publish

#define PUBLISHING 1
#define OPENMV A0
#define ON HIGH
#define OFF LOW

unsigned long stateTime = 0;
char data[120];

SYSTEM_MODE(MANUAL);
SYSTEM_THREAD(ENABLED);
//SYSTEM_MODE(SEMI_AUTOMATIC);

// Global objects
FuelGauge batteryMonitor;
const char * eventName = "FloodorNo";

SystemSleepConfiguration config;

// Various timing constants
const unsigned long MAX_TIME_TO_PUBLISH_MS = 20000; // Only stay awake for this time trying to connect to the cloud and publish
// const unsigned long TIME_AFTER_PUBLISH_MS = 4000; // After publish, wait 4 seconds for data to go out
const unsigned long SECONDS_BETWEEN_MEASUREMENTS = 360; // What should sampling period be?
const unsigned long EARLYBIRD_SECONDS = 0; // how long before desired time should I wake up? 
const unsigned long TIMEOUT_TINYCAM_MS = 20000;
String statement; 

void setup() {

  if (PUBLISHING == 1) {
    Particle.connect();
  } else {
    Cellular.off(); // turn off cellular for prelim testing (uncomment)
  }

  RGB.control(true); 
  RGB.color(0, 0, 0); //turns off status led 

  Serial.begin(9600);
  Serial1.begin(9600); // Initialize serial communication
  pinMode(A0, OUTPUT); 
  //digitalWrite(A0, HIGH); 

  Serial1.setTimeout(TIMEOUT_TINYCAM_MS);
  
}

void loop() {
  // Enter state machine
  switch (state) {

  case DATALOG_STATE: {
    Serial1.begin(9600);
    delay(100);
    openmv(ON); 
    delay(100); 
    if (Serial1.available() > 0) {
      statement = Serial1.readStringUntil('.'); 
      Serial.println(statement);
    }     
    real_time = Time.now();
    //float voltage = analogRead(A1) * .00133;
    // where .00133 = 3.3V / 4096 counts * ((R1 + R2) / R2) * ((R1 + R2) / R2) where R1 and R2 are in ohms 
    // e.g., analogRead(A1) * ((3.3/4096)*((2000000+1300000)/2000000)) 

    Serial1.end();
    delay(1000);
    Serial1.begin(9600);
    delay(100);
    Serial1.print(real_time); //Send its datetime to the openmv
    Serial.println(real_time);
    delay(1000);
    snprintf(data, sizeof(data), "%li,%s", //,%.02f", //,%.5f,%.5f,%.5f,%.5f,%.5f,%.02f,%.02f",
      real_time, statement.c_str()); //, voltage // if it takes a while to connect, this time could be offset from sensor recording
       

    delay(1000);
    // Print out data buffer
    Serial.println(data);
    Serial1.end(); 
    delay(1000); 
    openmv(OFF); 

    if (PUBLISHING == 1) {
      state = PUBLISH_STATE;
    } else {
      state = SLEEP_STATE;
    }

  }

  break;

  case PUBLISH_STATE: {

    // Prep for cellular transmission
    bool isMaxTime = false;
    stateTime = millis();

    while (!isMaxTime) {
      //connect particle to the cloud
      if (Particle.connected() == false) {
        Particle.connect();
        Serial.print("Trying to connect");
      }

      // If connected, publish data buffer
      if (Particle.connected()) {

        Serial.println("publishing data");

        // bool (or Future) below requires acknowledgment to proceed
        bool success = Particle.publish(eventName, data, 60, PRIVATE, WITH_ACK);
        Serial.printlnf("publish result %d", success);

        isMaxTime = true;
        state = SLEEP_STATE;
      }
      // If not connected after certain amount of time, go to sleep to save battery
      else {
        // Took too long to publish, just go to sleep
        if (millis() - stateTime >= MAX_TIME_TO_PUBLISH_MS) {
          isMaxTime = true;
          state = SLEEP_STATE;
          Serial.println("max time for publishing reached without success; go to sleep");
        }

        Serial.println("Not max time, try again to connect and publish");
        delay(500);
      }
    }
  }

  break;

  //Ready to sleep
  case SLEEP_STATE: {
    Serial.println("going to sleep");
    delay(500);

    // Sleep time determination and configuration
    int wakeInSeconds = secondsUntilNextEvent(); // Calculate how long to sleep 

    config.mode(SystemSleepMode::ULTRA_LOW_POWER)
      .gpio(D2, FALLING)
      .duration(wakeInSeconds * 1000L) // Set seconds until wake
      .network(NETWORK_INTERFACE_CELLULAR, SystemSleepNetworkFlag::INACTIVE_STANDBY); // keeps the cellular modem powered, but does not wake the MCU for received data

    // Ready to sleep
    SystemSleepResult result = System.sleep(config); // Device sleeps here

    // It'll only make it here if the sleep call doesn't work for some reason (UPDATE: only true for hibernate. ULP will wake here.)
    Serial.print("Feeling restless");
    stateTime = millis();
    state = DATALOG_STATE;
  }
  break;
  }
}

int secondsUntilNextEvent() {

  int current_seconds = Time.now();
  int seconds_to_sleep = SECONDS_BETWEEN_MEASUREMENTS - (current_seconds % SECONDS_BETWEEN_MEASUREMENTS) - EARLYBIRD_SECONDS;

  Serial.print("Sleeping for ");
  Serial.println(seconds_to_sleep);

  return seconds_to_sleep;
}

void openmv(byte state)
{
  digitalWrite(OPENMV, state);
  delay(50);
}

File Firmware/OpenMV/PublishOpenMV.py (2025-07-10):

# Untitled - By: ebgoldstein - Wed Feb 14 2024
## Adding edits by combining senior design teams and EBG's - Liz Farquhar 6/18/2024
# EBG clean up 7/23/24
# LF turned off the external pin interrupt 8/1/2024
# LF changed tl to the ml library and cleaned up unused functions 7/10/2025

import sensor, time, pyb, gc, os, uselect, ml
from pyb import UART

# Set the threshold for detecting dark images
brightness_threshold = 10  # Adjust this value as needed

#load the TF lite micro file
net = ml.Model('MNv2Flood_cat_Mar2025.tflite',load_to_fb=True)
labels = ['Flood', 'NoFlood']

uart = UART(1, 9600) # UART1, adjust baudrate as needed

def callback(line):
    pass

def get_today_folder():
    ts = int(curr_time) #time from boron
    tsdt = list(time.localtime(ts)) #convert from tuple to list
    tsdt[0] = (int(tsdt[0])-30) #subtract 30 years bc micropython starts timestamps at 2000
    date_str = f"{tsdt[0]}-{tsdt[1]}-{tsdt[2]}" #extract date
    folder_path = f"{date_str}"
    if not folder_path in os.listdir():
        os.mkdir(folder_path)
    return folder_path

while(True):
    #Reinitialize the sensor after sleep
    sensor.reset() # Initialize the camera sensor.
    sensor.set_pixformat(sensor.RGB565)
    sensor.set_framesize(sensor.QVGA)
    sensor.skip_frames(time = 2000)

    #TAKE PIC
    img = sensor.snapshot()

    # Calculate the average brightness of the image
    avg_brightness = img.get_statistics().mean()

    # Check if the image is too dark. if not, classify
    if avg_brightness > brightness_threshold:
        TF_objs = net.predict([img])
        Flood = TF_objs[0][0][0]
        NoFlood = TF_objs[0][0][1]
        if Flood > NoFlood:
            #print('Flood')
            uart.write('Flood.')
            pyb.delay(1500)
            floodstate = "Flood"
        else:
            #print('No Flood')
            uart.write('No Flood.')
            pyb.delay(1500)
            floodstate = "NoFlood"
    else:
        #print('Too Dark')
        uart.write('Too Dark.')
        pyb.delay(1500)
        floodstate = "TooDark"

    print(floodstate)

    #COMMS via UART
    pyb.delay(1000);

    poll = uselect.poll()
    poll.register(uart, uselect.POLLIN)
    poll.poll()
    curr_time = uart.read().decode('utf-8')
    file_name = curr_time + floodstate

    today_folder = get_today_folder()

    with open("./DataLog.txt", 'a') as file:
        file.write(curr_time + "," + floodstate + "," + str(gc.mem_alloc()) + "\n")

    img.save("./" + today_folder + "/" + file_name + ".jpg")

    # run garbarge collection to prevent memory growth
    #del img
    gc.collect()

    # Begin power down ------------------------------------
    # Shutdown the sensor (pulls PWDN high).
    sensor.shutdown(True)
    # Enter lightsleep Mode
    #machine.lightsleep()

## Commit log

2024-04-04 Rename Circuit-Diagram.png to Circuit Diagram/Circuit-Diagram.png
2024-04-09 Adding the voltage divider firmware
2024-04-24 Getting the voltage reader to work
    removed the batteryMonitor functions and added function to read the solar panel voltage off of pin A1 on the boron. Still taking suggestions for how to calculate the percentcharge though - that isn't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
2024-04-26 Updating the code to remove voltage percentage
2024-06-04 Scaling the voltage divider back up
    Scaled it back up to be out of 5V to make the published voltage value more digestible
2024-06-12 prevent memory growth (#14)
    [PublishOpenMV.py]
2024-06-21 Added save.image and framework for the datetime
2024-06-25 Added datetime communication and file logging
    OpenMV now saves the images, receives the datetime from the Boron, and save a .txt file with datetime and flood/noflood. It takes the boron one or two cycles after connecting to cellular for everything to work nicely. In the future, it would be nice to have some code where it saves the last known datetime and goes off of that for the curr_time if cellular fails. Also I need to review the voltage divider
    [PublishOpenMV.py, TestingDatetime.py, TestingSendingDatetime.cpp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]
2024-07-01 Changed the voltage divider to a constant 0.00133
2024-07-11 Reorganizing
    Firmware for testing aspects of the development (e.g., voltage divider or publishing) have been moved to "Development" folder
2024-07-22 Fixed the str and filename inconsistency
    [PublishOpenMV.py]
2024-07-22 Update PublishOpenMV.py
    re-init the camera in the loop, to deal with sleeping... (idea from @SUPScientist 's digging in forums
2024-07-22 OpenMVFix
    Fixed openmv code and worked with Evan to clean up code
    [PublishOpenMV.py, TinyCamPublish.ino]
2024-07-22 switching boron code back to publish
    accidentally pushed it with cellular off - turned it back on
2024-07-22 Delete hardware/baseplate_v5.stl
    adding new baseplate design
    [baseplate_v5.stl]
2024-07-22 new baseplate
    updates
    [baseplate_v6.stl]
2024-07-22 Add files via upload
    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
    [antenna_mount_v4.stl]
2024-07-23 Update PublishOpenMV.py
    i tried to streamline the if/else and the uart comms
2024-07-26 Delete assets/Circuit-Diagram.png
    Adding a new one
2024-07-26 Adding new circuit diagram
2024-07-30 Added the mosfet switch and function
2024-08-01 Added updated BOM
    [List of Materials.xlsx]
2024-08-01 reorganizing the hardware folder
    [XY_bracket_v4.stl, antenna_mount_v4.stl, baseplate_v6.stl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]
2024-08-06 mv 3d printed folder
    [XY_bracket_v4.stl, antenna_mount_v4.stl, baseplate_v6.stl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]
2024-08-12 add simple google sheets parser
    [TinyCamML - Sheet1 - 20240812.csv]
2024-08-12 update parser with met data
    [3771385.csv, TinyCamML - Sheet1 - 20240812.csv]
2024-08-20 Added CAD files
    [Visor.ipt, XY_part.ipt, antenna_mount.ipt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]
2024-09-05 Adding updated circuit without voltage divider
2024-09-05 Adding updated circuit without voltage divider
    Slightly better quality
2024-09-05 Commented out voltage divider code
2024-09-17 Most updated part
    [XY_part _v4.stl]
2024-10-17 Deleted extra curr_time definition
    The polling for curr_time was done twice so it didn't log properly. I just deleted one of them.
    [PublishOpenMV.py]
2024-11-25 Turned off boron status led
    To make it less noticeable in dark places at night
2024-12-02 updated BOM
    [2024_12_02_List_of_Materials.xlsx]
2025-01-07 Create README.md
    Created directory for PCB components
2025-01-07 Added Board Eagle Files, Schematics, and BoM
    [TinyCam Carrier Board.brd, TinyCam Carrier Board.sch, TinyCam PCB BoM.xlsx]
2025-01-07 Updated circuit diagram image from Issue
    https://github.com/TinyCamML/TinyCamML/issues/34#issuecomment-2575946399
2025-01-07 Updated board to denote dimension units
    [TinyCam Carrier Board.brd]
2025-01-10 Updated PCB layout to accomodate for SD card slot
    [TinyCam Carrier Board.brd]
2025-01-10 Delete hardware/PCB/TinyCam Carrier Board_2025-01-07.zip
    Deleted CAM files for old PCB layout
2025-02-04 Fixed OpenMV pin distance
    Updated board layout, brd file, and CAM data with corrected 32.26mm pin to pin distance for the OpenMV H7 Plus.
    [TinyCam Carrier Board.brd]
2025-02-04 Delete hardware/PCB/TinyCam Carrier Board_2025-01-10.zip
    Removed CAM data for PCB with incorrect OpenMV pin distance.
2025-03-13 Adding build guide without PCB Board
2025-04-12 New Baseplate
    [baseplate_pcb_final.stl]
2025-06-23 BOM to include newest baseplate and the PCB board
    [2025_06_23_BillofMaterials.xlsx]
2025-07-02 Updated BOM to exclude jumper cables for PCB vers.
    [2025_07_02_BillofMaterials.xlsx]
2025-07-10 Updated tl library to ml
    Because of a recent firmware update to OpenMV, the previous tl.load() is no longer supported so we have to run our ml models using the ml library.
    [PublishOpenMV.py]
2025-07-14 older code just in case
    we shoudl retain this older code, and not overwrite it - it worked for that version of firmware
2025-08-05 Add files used to create figures in manuscript
    [CB01Datalog.csv, CB02Datalog.csv, CB03Datalog.csv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]

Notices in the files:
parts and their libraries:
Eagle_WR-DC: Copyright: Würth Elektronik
